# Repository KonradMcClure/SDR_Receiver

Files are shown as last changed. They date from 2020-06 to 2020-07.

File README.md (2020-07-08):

# Low-Cost Software Defined Radio Receiver
The goal of this project was to design a low-cost software-defined radio (SDR) receiver. This project was done for my Walla Walla University Electronics II course with my partner [Caleb Froelich](https://github.com/froeca).

## Design Objectives
Our professor, [Dr. Rob Frohne](https://github.com/frohro), gave us the following design objectives:
  1. Minimum discernible signal less than 1 uV
  2. Good image rejection
  3. Low noise figure
  4. Inexpensive to build ($25 component budget)
  
My partner, Caleb, and I set our own design objectives as well to help narrow down the design we settled on:
  1. **Simple Design**: We wanted our design to be easy to understand and construct. As such we avoided using transformers and used a Tayloe Mixer which has a relatively easy to understand design.
  2. **Ease of Construction**: Since this class took place during an online quarter due to COVID-19, we wanted to make sure construction wouldn't be too difficult without the usual tools we have in our lab. This decision shaped our board layout and part selection (picking through-hole parts as opposed to surface-mount when possible).
  3. **Ease and Quality of Amplification**: Most of the cost that goes into the board went into getting good, low-noise operational amplifiers. The instrumentation amps we chose use a single resistor to set the gain, making it easy to switch out and test different gain values.

## Overview
The Software Defined Radio (SDR) receiver connects to an antenna and covers the filtering, mixing, and amplification of the desired signal. It then connects a sound card within a computer and software handles the demodulation of the signal into playable audio. The mixing is handled using an Arduino Nano running code provided to us by our Professor, [Dr. Rob Frohne](https://github.com/frohro), which interfaces with [Quisk](https://james.ahlstrom.name/quisk/), an SDR that controls the receiver through the Arduino. Using Quisk, the radio can be tuned to a certain frequency by adjusting the speed of the local oscillator used in the mixing process. Our budget on this project to keep with the low-cost aspect was about $30 including fabrication of the PCB and the required components. 

# Theory
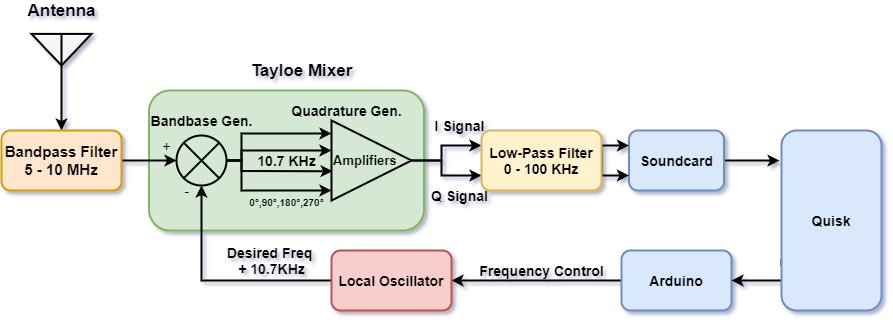
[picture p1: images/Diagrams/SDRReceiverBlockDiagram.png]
Circuit Block Diagram

The basics of the SDR Receiver are shown above in the block diagram, with the blue components being defined by software. An antenna picks up the radio signal and passes it through a bandpass filter. This filter will attenuate any signals outside our desired range of 5 – 10 MHz. This is then passed through a Tayloe Mixer, also known as the Tayloe Quadrature Product Detector. The Tayloe Mixer is a simple and efficient mixer that uses a 1:4 demultiplexer and operational amplifiers to generate the I and Q quadrature signals for demodulation. After the signal has been split into four bandbase signals, they are amplified and combined into the I and Q quadrature signals. Those signals go through a final Low-Pass filter that will attenuate signals above 100KHz in frequency, effectively smoothing the output signal. This signal is then sent via 3.5mm audio cable to the soundcard which demodulates the signal. Quisk can then read the input from the sound card and play it. Quisk also interfaces to the Arduino Nano to set the speed of the local oscillator for tuning into the desired frequency.

# Rev 2 Design
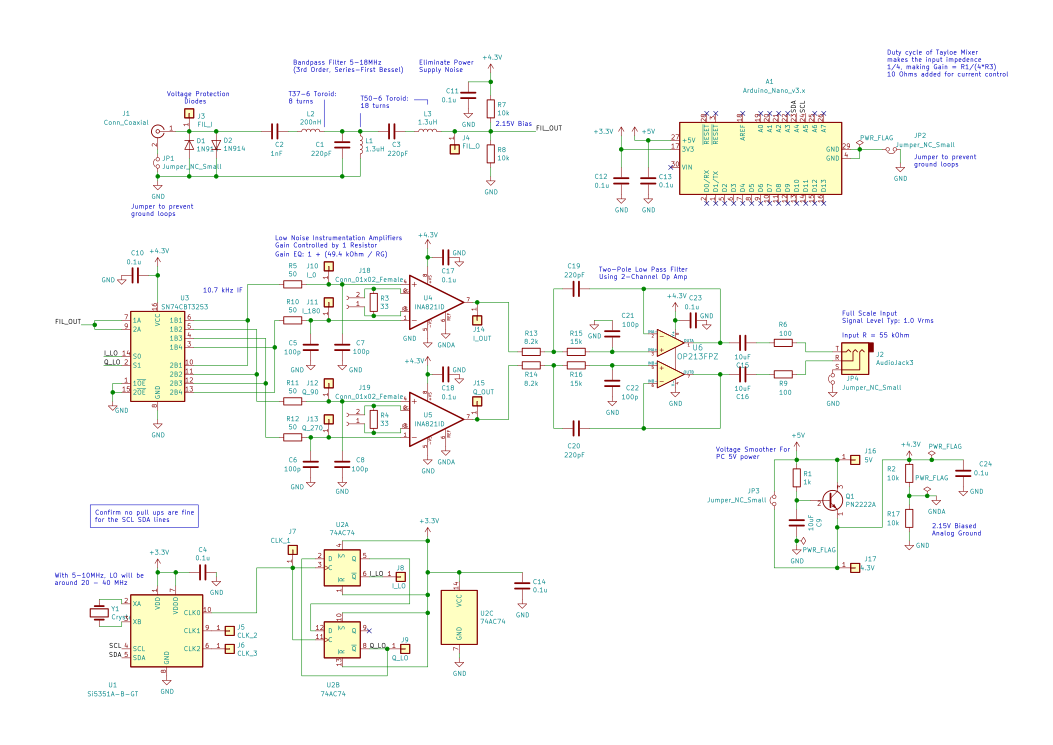
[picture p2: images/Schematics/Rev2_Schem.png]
Rev 2 Schematic


Here is the full design schematic, which we'll break down piece by piece below. You can look at the full image [here](https://github.com/KonradMcClure/SDR_Receiver/blob/master/images/Schematics/Rev2_Schem.svg) or download the [KiCad](https://kicad-pcb.org/) project [here](https://github.com/KonradMcClure/SDR_Receiver/tree/master/SDRReciever) to take a closer look yourself.

This page is also acting as a report of the design we had for our class project. If the design is continued on in the future, I will likely move this description to the Wiki and update it with the new one.

## Bandpass Filter
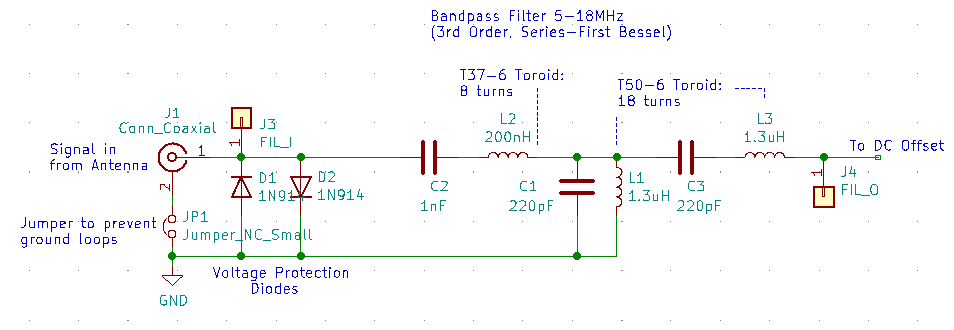
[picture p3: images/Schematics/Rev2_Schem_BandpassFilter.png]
Bandpass Filter Rev2


The bandpass filter is a 3rd-Order, Series-First, Bessel filter that was generated using the RF Tools LC Filters Design Tool. It is designed to have input and output impedances of 50 Ω. The motivation to use a series-first configuration came from the capacitor C2 acting as a blockade for any DC signal coming in through the antenna. This would allow us better control over the DC voltage offset that is later required for our single-supply op-amps. 

## DC Voltage Offset
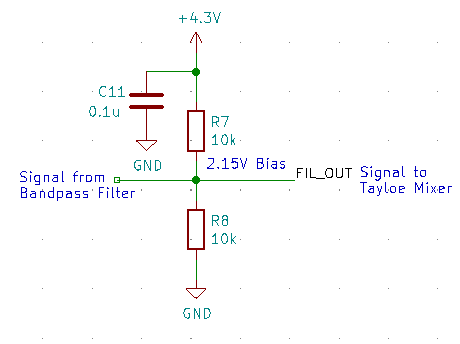
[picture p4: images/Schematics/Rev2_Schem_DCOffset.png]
DC Voltage OFfset Rev 2


Since we didn't want to create a negative supply for our op-amps, we opted for using them with a single supply and giving our signal a DC offset that sits in the middle between the 4.3V supply and ground. This offset was done via a simple voltage divider of two 10k resistors from 4.3V to GND.

## Tayloe Mixer 
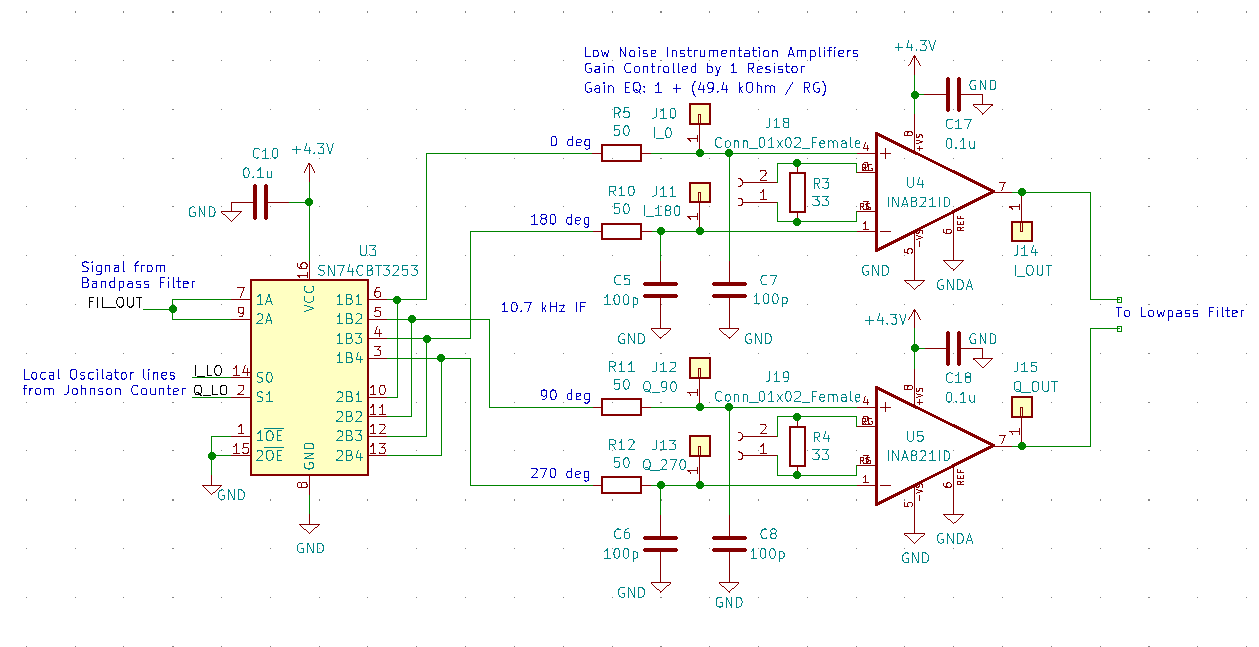
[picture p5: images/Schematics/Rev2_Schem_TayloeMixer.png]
Tayloe Mixer Rev 2


The Tayloe Mixer is a mixer design as seen in [this paper](http://www.norcalqrp.org/files/Tayloe_mixer_x3a.pdf) by Dan Tayloe. We chose it due to its relatively simple and elegant design. It utilizes a [two-channel SN74CBT multiplexer](http://www.ti.com/lit/ds/symlink/sn74cbt3253.pdf?ts=1591655665924) and a pair of [INA821ID single gain resistor instrumentation amplifiers](http://www.ti.com/lit/ds/symlink/ina821.pdf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). To be more specific, Tayloe describes this as a "switching integrator," rather than a mixer, since a mixer normally produces both a sum and difference frequency of the RF and LO signals, while this design only produces the difference frequency. Acknowledging this, I am going to refer to it as a mixer for simplicity.

### Multiplexer
The [SN74CBT multiplexer](http://www.ti.com/lit/ds/symlink/sn74cbt3253.pdf?ts=1591655665924) acts as a [product detector](https://en.wikipedia.org/wiki/Product_detector), converting the RF signal into four baseband signals. The switching speed of the MUX is set by the local oscillator, which is a divide by 4 circuit created from a 2-bit Johnson counter seen below. This speed is set to be the RF frequency + 10.7kHz. The sampling capacitors shown between the MUX and instrumentation amps will follow the voltage level of the signal while its line's switch is active, and then hold that value while the switch is closed. This will occur on four different lines, outputting four bandbase signals at phases of 0°, 90°, 180°, and 270°. 

### Instrumentation Amplifiers
The [INA821ID Instrumentation Amplifiers](http://www.ti.com/lit/ds/symlink/ina821.pdf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) act as differential summers of the 0° and 180° signals, and the 90° and 270° signals. This is because the information between the two signals within the two pairs are redundant to each other. Summing 0° and 180° will get us our In-Phase (I) signal and summing the 90° and 270° signals will get us our Quadrature (Q) signal.

## Lowpass Filter
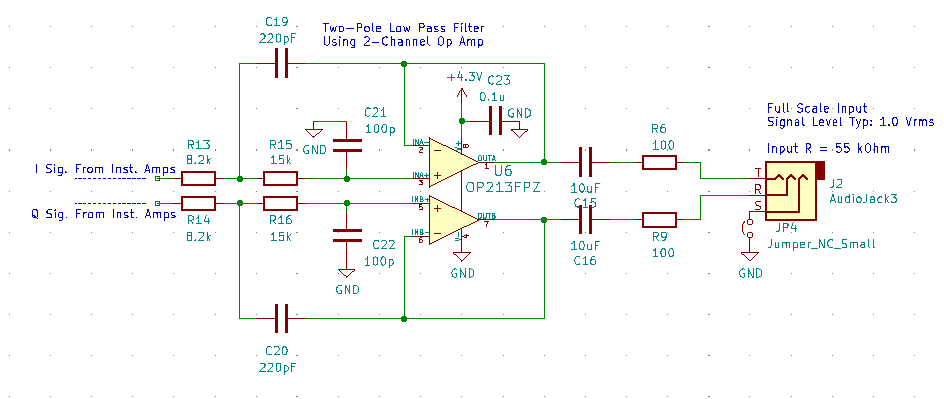
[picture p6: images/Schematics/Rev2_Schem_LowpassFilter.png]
Lowpass Filter


Now that we have our I and Q signals, we'll send them through a Lowpass filter that will attenuate the high frequencies that may still remain in the signal, effectively smoothing it out. For this we used an [OP213FPZ op amp](https://www.analog.com/media/en/technical-documentation/data-sheets/OP113_213_413.pdf), which has 2-channel produces low noise. We used the [Texas Instruments Filter Design Tool](https://webench.ti.com/filter-design-tool/) to generate this as a two-pole filter with a 100kHz cutoff and no gain.

## Voltage Smoother and Analog Ground Reference
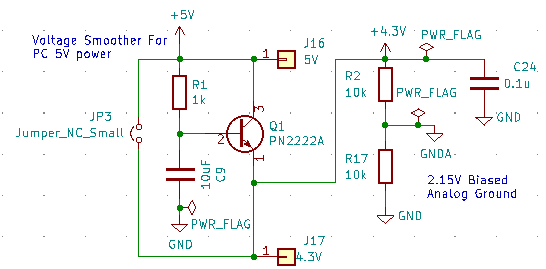
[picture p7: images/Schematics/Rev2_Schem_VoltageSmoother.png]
Voltage Smoother Rev2


Professor Rob Frohne suggested that we all use a BJT to smooth the voltage coming from the computer, since all the rapid switching that happens in computers tends to create a lot of noise. He measured the output voltage to be about 4.3V based on the design on [his GitHub](https://github.com/frohro/IQ_SDR) , so we followed his example and designed ours the same way.

# Simulation
We simulated each of our main parts in LTspice to confirm our design. Some things, 

## Bandpass Filter Simulation
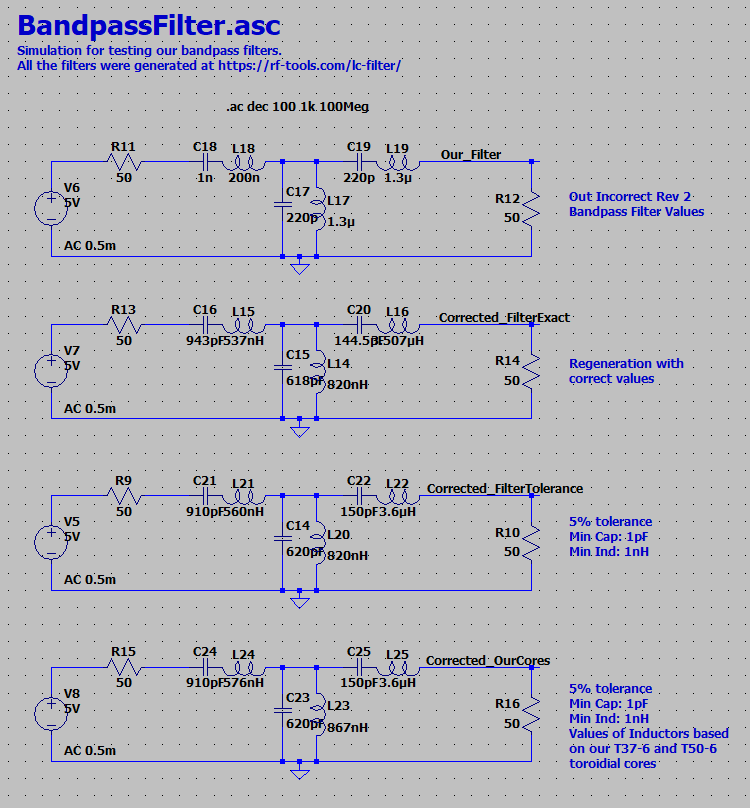
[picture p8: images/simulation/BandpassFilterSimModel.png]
Bandpass Filter Simulation Model

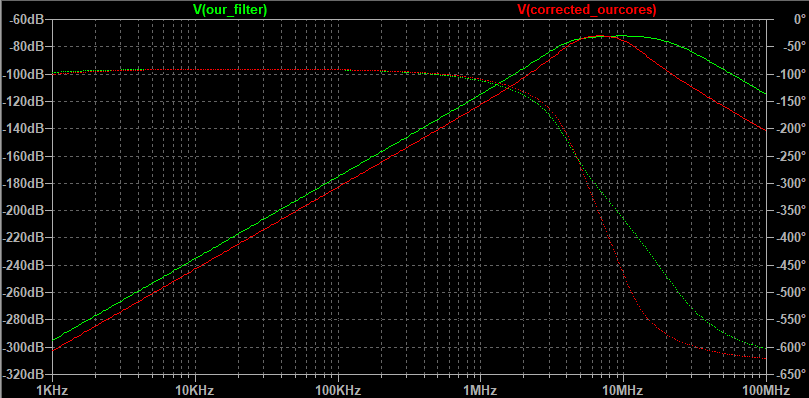
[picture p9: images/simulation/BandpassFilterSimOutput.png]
Bandpass Filter Simulation Output


First we simulated the bandpass filter to check it's response. As seen here, and as mentioned later, our bandpass filter for Rev 2 got it's values messed up, which led to a similar, but incorrect response. We re-ran the RF Tools filter design and retested the response of our new filter in LTspice. As can be seen above, the response is much better. The filter on the bottom is calculated with 5% tolerances on all the components and then adjusted for the same toroids that we were provided by our professor. The differences between the bottom three are neglible, so only our current filter and the final adjusted one is plotted.

## Lowpass Simulation
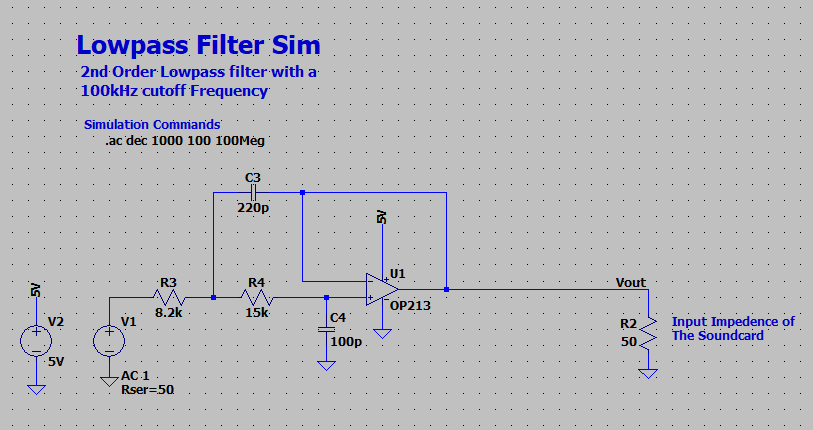
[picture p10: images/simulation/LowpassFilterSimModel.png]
Lowpass Filter Simulation Model

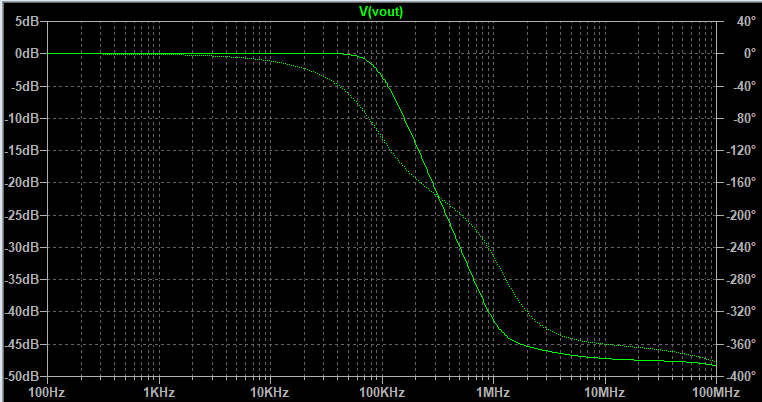
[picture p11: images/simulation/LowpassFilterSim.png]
Lowpass Filter Simulation Output


We also tested out our lowpass filter. Luckily LTspice had the OP213's built-in, so we were confident in the results. We can see that the cutoff is at 100kHz as we expected. 

## Full Design Simulation
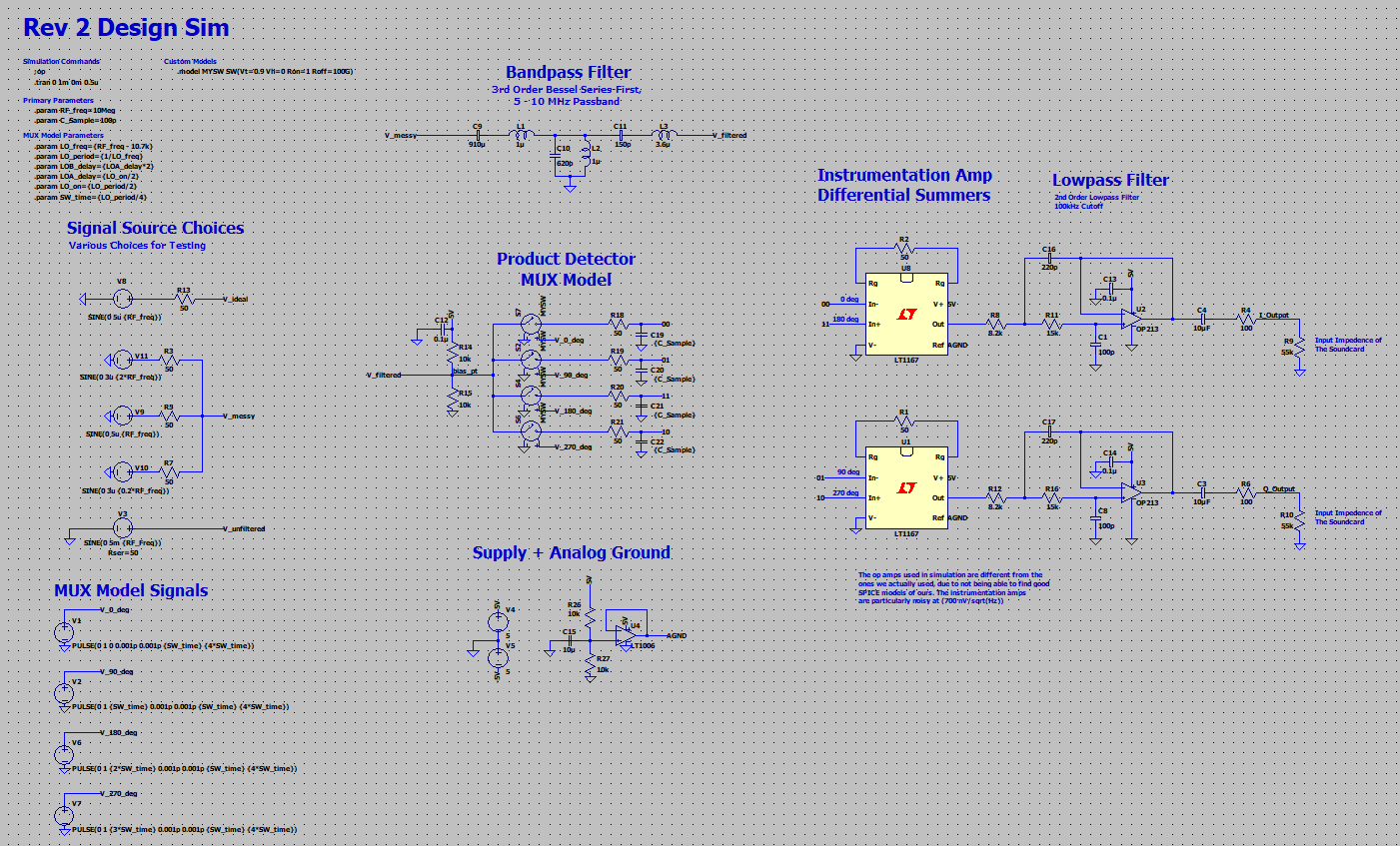
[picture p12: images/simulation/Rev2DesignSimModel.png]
Full Rev 2 Simulation Model


With the two filters out of the way, we can assemble the components inbetween. We have created a model for the mux using four voltage controlled switches, and four voltage pulses that control them in the same manner that the Johnson counter will. For instrumentation amps, we used LT1167s because they didn't take as long to simulate as long as ones we tried to import. The LT1167's had a much higher noise profile than the INA821's we selected, so we figured if we could get these to work, the INA821's would work great. below you can see the baseband signals and the I and Q outputs. They're exactly as we'd like to see them, about 90 degrees out of phase and at a frequency of about 10.8kHz.

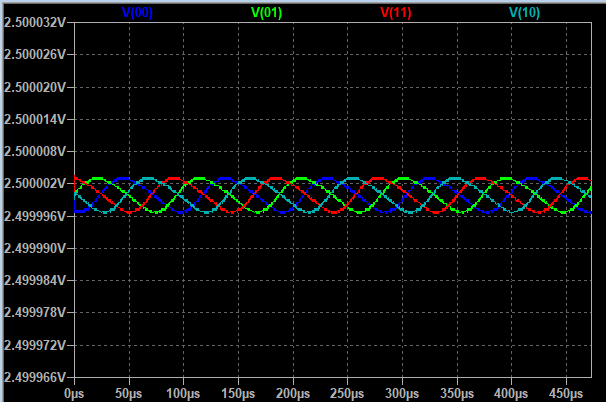
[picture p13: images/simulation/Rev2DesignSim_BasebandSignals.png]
Full Rev 2 Simulation Baseband Output

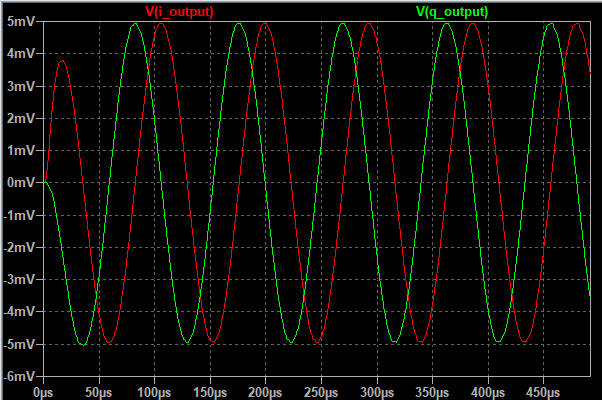
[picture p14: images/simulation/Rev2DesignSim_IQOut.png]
Full Rev 2 Simulation I and Q Output


# PCB Design
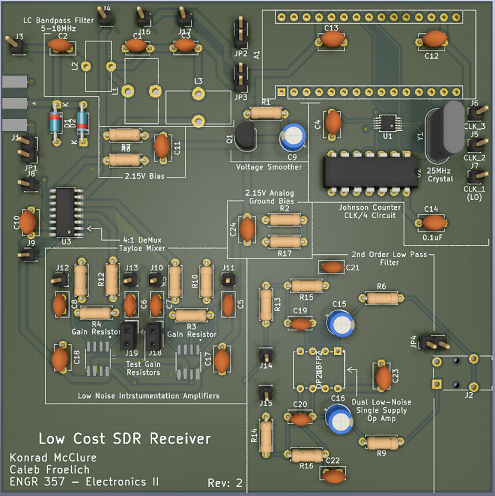
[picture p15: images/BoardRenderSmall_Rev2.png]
Board Render


We sourced our board from [JLCPCB](https://jlcpcb.com/), who had an offer going of 5, 2-layer, 100x100mm boards for $2. With that size in mind, my partner and I both did our own board layouts and compared after to decide which to send in for printing. We wanted to be sure to match the impedance of the antenna all the way through to the instrumentation amps, so we used the PCB Calculator in KiCad to find the trace width we needed: 1.064mm. The input to the calculator can be seen here:
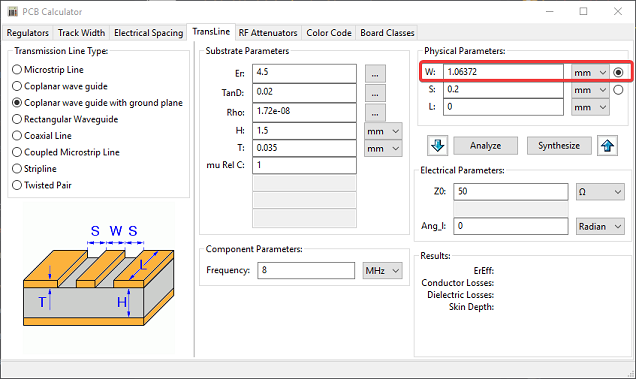
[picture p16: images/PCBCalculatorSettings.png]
PCB Calculator Screen


We got the rest of the information, such as the substrate parameters, from [JLCPCB's Capabilities page](https://jlcpcb.com/capabilities/Capabilities). The design shown above was mine, doing my best to keep traces relatively short and straight and parts close to the next. However...

# Construction and Testing
The PCB layout we decided to print was my partner's who had a layout with really nice divisions between sections, which we believed would be easier for testing. You can find that layout on [his GitHub page](https://github.com/froeca/Software-Defined-Radio). All of the components are exactly the same, only the layout is different.

Before receiving the parts from Dr. Frohne, JLCPCB, and Digikey, we put together a Construction and Testing plan which can be found in the documents folder of this repository. This plan wasn't followed exactly to the T during our assembly, but it was an important step for us thinking through the process and how to best assemble the sections so that we could test them in isolation before connecting them together.

# Testing
For info on the testing of the project, head over to the [Testing page on the Wiki](https://github.com/KonradMcClure/SDR_Receiver/wiki/Rev-2-Testing)!

# Quisk Setup
Loading the Arduino Nano with the OpenRadio software found [here](\Arduino\PSK), I opened the quisk_conf_openradio.py file and change the info in the SERIAL PORT SETTINGS sections to the COM# port that my Arduino is plugged into. This was found in Device Manager on Windows 10. In Device Manager, I also right clicked the COM port and went to Properties > Port Settings and changed the Bits per second to 57600 to match the value in the config file.

After opening Quisk, I went to Config > Radios and added a radio of the type SoftRock Fixed and named it MyRadioBoy (not necessary), setting it to open to that new radio. Under the new MyRadioBoy tab and Hardware subtab, I changed the Hardware File Path to point to the quisk_conf_openradio.py in the repository. Then in the Sound subtab, I made sure the I/Q Rx Sample Input was set to the sound card input that my 3.5mm cable was connected to from the board.

# Results!
Sending in a 8MHz test frequency, I could see that the image rejection was pretty good, but I went to the Config tab and clicked the "Adjust receive amplitude and phase" button. **I adjusted the levels for the best image rejection I could get, dropping the image down to about the same level as the spurious signals.**

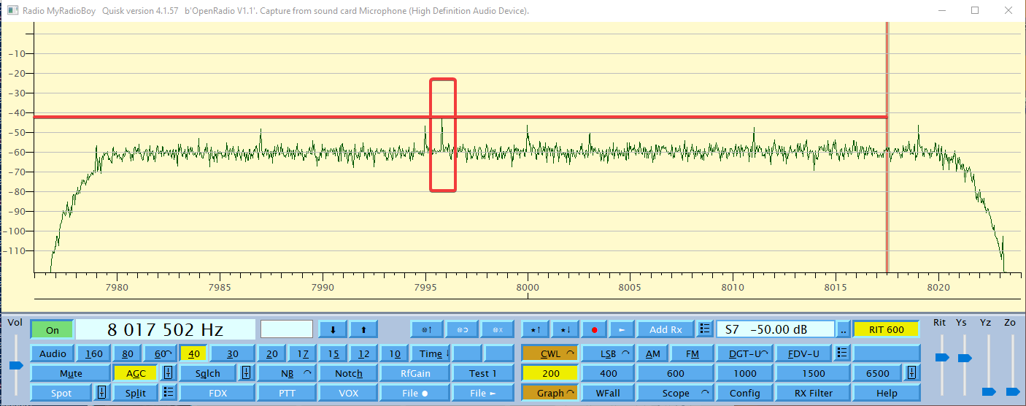
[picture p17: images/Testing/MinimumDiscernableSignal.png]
Minimum Discernable Signal Test

Then, using a step attenuator Caleb and I designed before this radio, I input a 50uV 8MHz signal to the receiver and attenuated it by 40dB, which was just higher than the spurious signals. **From this I concluded our minimum discernable signal was about 0.5uV.**

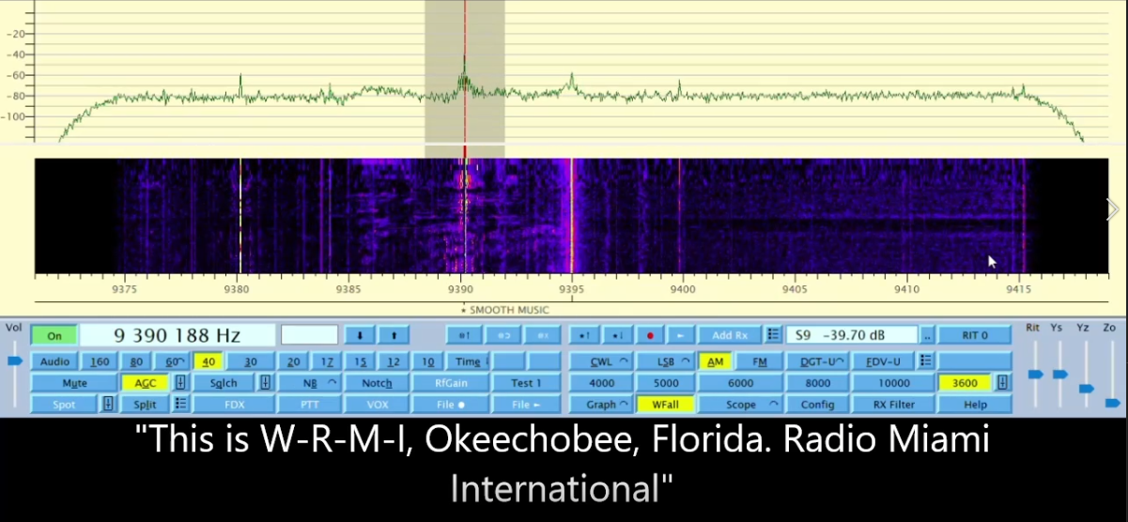
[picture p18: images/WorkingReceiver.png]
It works!

After stringing a wire out to my roof as an antenna (about 50ft up or so) and soldering one end to an SMA connector, I connected it to the board. While not the clearest, it picks up signals pretty well! [You can see some signals that I was able to receive here!](https://github.com/KonradMcClure/SDR_Receiver/tree/master/video)

# Credits
My teammate [Caleb Froelich](https://github.com/froeca), who has [his own repository of this project](https://github.com/froeca/Software-Defined-Radio).

My professor [Dr. Rob Frohne](https://github.com/frohro), who provided us with an example of a similar [project of his own here](https://github.com/frohro/IQ_SDR)!

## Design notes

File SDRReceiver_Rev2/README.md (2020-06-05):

# SDR_Receiver
Software Defined Radio Receiver designed together with Caleb Froelich for our Walla Walla University Electronics II project.

## Board Design
IMAGE

Designed on a 100mm x 100mm Board...

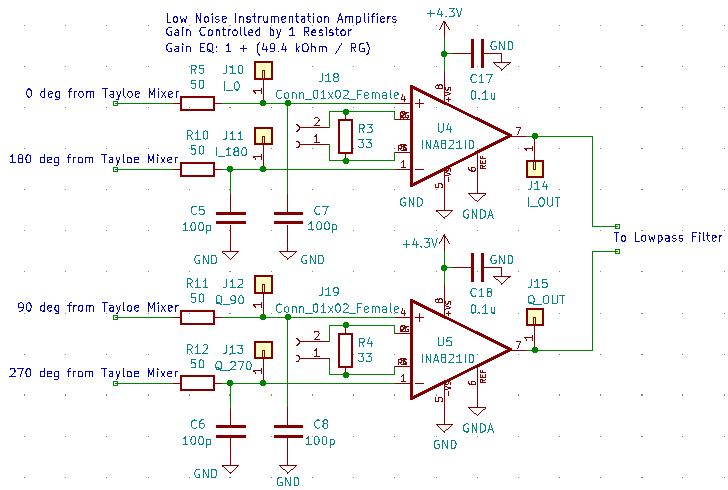
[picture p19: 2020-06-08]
images/Schematics/Rev2_Schem_InstAmps.png

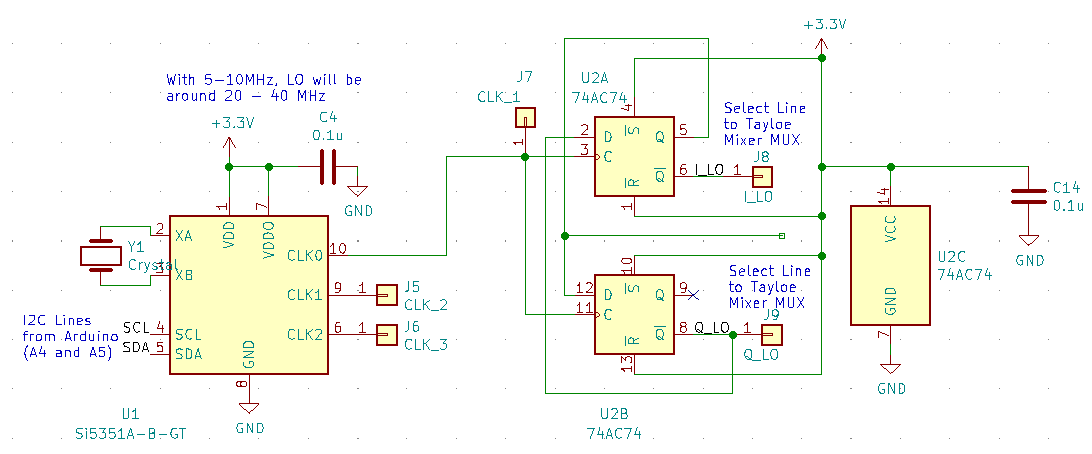
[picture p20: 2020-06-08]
images/Schematics/Rev2_Schem_CLKGenAndDiv4.png

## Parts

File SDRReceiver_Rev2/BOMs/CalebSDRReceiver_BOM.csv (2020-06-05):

Manufacturer Part Number | Manufacturer | Digi-Key Part Number | Customer Reference | Reference Designator | Packaging | Part Status | Quantity | Unit Price | Extended Price | Quantity Available | Mfg Std Lead Time | Description | RoHS Status | Lead Free Status | REACH Status
ATS250 | CTS-Frequency Controls | CTX419-ND | Caleb Froelich (1/12) 1pc |  | Bulk | Active | 1 | 0.37 | $0.37 | 238 | 12 Weeks | CRYSTAL 25.0000MHZ SERIES T/H | ROHS3 Compliant | Lead free | REACH Unaffected
INA821IDR | Texas Instruments | 296-INA821IDRCT-ND | Caleb Froelich (2/12) 2pc |  | Cut Tape (CT) | Active | 2 | 5.15 | $10.30 | 1963 | 6 Weeks | OP AMP | ROHS3 Compliant | Lead free | Not Available
SR215C104KAR | AVX Corporation | 478-3188-ND | Caleb Froelich (3/12) 10pc |  | Bulk | Active | 10 | 0.135 | $1.35 | 8242 | 11 Weeks | CAP CER 0.1UF 50V X7R RADIAL | ROHS3 Compliant | Lead free | REACH Unaffected
K101K15C0GF53L2 | Vishay BC Components | BC5130-ND | Caleb Froelich (4/12) 6pc |  | Bulk | Active | 6 | 0.22 | $1.32 | 6218 | 10 Weeks | CAP CER 100PF 50V C0G/NP0 RADIAL | ROHS3 Compliant | Lead free | Not Available
SI5351A-B-GT | Silicon Labs | 336-2399-5-ND | Caleb Froelich (5/12) 1pc |  | Tube | Active | 1 | 0.92 | $0.92 | 1436 | Not Available | IC CLK GENERATOR 200MHZ 10MSOP | Not Available | Lead free | Not Available
SN74AC74N | Texas Instruments | 296-4342-5-ND | Caleb Froelich (6/12) 1pc |  | Tube | Active | 1 | 0.55 | $0.55 | 811 | 6 Weeks | IC FF D-TYPE DUAL 1BIT 14DIP | ROHS3 Compliant | Lead free | REACH Unaffected
8.6002E+11 | Würth Elektronik | 732-8820-1-ND | Caleb Froelich (7/12) 3pc |  | Cut Tape (CT) | Active | 3 | 0.1 | $0.30 | 2960 | 28 Weeks | CAP ALUM 10UF 20% 25V RADIAL | ROHS3 Compliant | Lead free | REACH Unaffected
SN74CBT3253CDR | Texas Instruments | 296-19206-1-ND | Caleb Froelich (8/12) 1pc |  | Cut Tape (CT) | Active | 1 | 0.58 | $0.58 | 5969 | 6 Weeks | IC MUX/DEMUX DUAL 4:1 16SOIC | ROHS3 Compliant | Lead free | REACH Unaffected
OP213FPZ | Analog Devices Inc. | OP213FPZ-ND | Caleb Froelich (9/12) 1pc |  | Tube | Active | 1 | 7.47 | $7.47 | 334 | 8 Weeks | IC OPAMP GP 2 CIRCUIT 8DIP | ROHS3 Compliant | Lead free | REACH Unaffected
PN2222ATF | ON Semiconductor | PN2222ATFCT-ND | Caleb Froelich (10/12) 1pc |  | Cut Tape (CT) | Active | 1 | 0.24 | $0.24 | 7314 | 19 Weeks | TRANS NPN 40V 1A TO-92 | ROHS3 Compliant | Lead free | REACH Unaffected
D102K20Y5PH63J5R | Vishay BC Components | BC5111-ND | Caleb Froelich (11/12) 1pc |  | Bulk | Active | 1 | 0.18 | $0.18 | 16259 | 10 Weeks | CAP CER 1000PF 100V Y5P RADIAL | ROHS3 Compliant | Lead free | Not Available
K221K10X7RF5UH5 | Vishay BC Components | BC2672CT-ND | Caleb Froelich (12/12) 4pc |  | Cut Tape (CT) | Active | 4 | 0.19 | $0.76 | 13768 | 10 Weeks | CAP CER 220PF 50V X7R RADIAL | ROHS3 Compliant | Lead free | Not Available

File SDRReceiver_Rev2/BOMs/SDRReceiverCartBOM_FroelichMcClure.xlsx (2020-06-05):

 | Digikey BOM - Konrad McClure and Caleb Froelich
 | Cart Link | https://www.digikey.com/short/zzpdh8
Index | Quantity | Part Number | Manufacturer Part Number | Description | Customer Reference | Available | Backorder | Unit Price | Extended Price USD
1 | 1 | CTX419-ND | ATS250 | CRYSTAL 25.0000MHZ SERIES T/H |  | 1 | 0 | $0.37 | $0.37
2 | 2 | 296-INA821IDRCT-ND | INA821IDR | OP AMP |  | 2 | 0 | 5.15 | 10.30
3 | 10 | 478-3188-ND | SR215C104KAR | CAP CER 0.1UF 50V X7R RADIAL |  | 10 | 0 | 0.14 | 1.35
4 | 6 | BC5130-ND | K101K15C0GF53L2 | CAP CER 100PF 50V C0G/NP0 RADIAL |  | 6 | 0 | 0.22 | 1.32
5 | 1 | 336-2399-5-ND | SI5351A-B-GT | IC CLK GENERATOR 200MHZ 10MSOP |  | 1 | 0 | 0.92 | 0.92
6 | 1 | 296-4342-5-ND | SN74AC74N | IC FF D-TYPE DUAL 1BIT 14DIP |  | 1 | 0 | 0.55 | 0.55
7 | 3 | 732-8820-1-ND | 860020472003 | CAP ALUM 10UF 20% 25V RADIAL |  | 3 | 0 | 0.10 | 0.30
8 | 1 | 296-19206-1-ND | SN74CBT3253CDR | IC MUX/DEMUX DUAL 4:1 16SOIC |  | 1 | 0 | 0.58 | 0.58
9 | 1 | OP213FPZ-ND | OP213FPZ | IC OPAMP GP 2 CIRCUIT 8DIP |  | 1 | 0 | 7.47 | 7.47
10 | 1 | PN2222ATFCT-ND | PN2222ATF | TRANS NPN 40V 1A TO-92 |  | 1 | 0 | 0.24 | 0.24
11 | 1 | BC5111-ND | D102K20Y5PH63J5R | CAP CER 1000PF 100V Y5P RADIAL |  | 1 | 0 | 0.18 | 0.18
12 | 4 | BC2672CT-ND | K221K10X7RF5UH5 | CAP CER 220PF 50V X7R RADIAL |  | 4 | 0 | $0.19 | $0.76
 |  |  |  |  |  |  |  | TOTAL: | $24.34

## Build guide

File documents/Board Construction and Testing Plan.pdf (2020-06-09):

Caleb Froelich | ENGR 357
Konrad McClure
05/07/2020

### Board Construction and Testing Protocol

Prep-Work
- Prepare documentation

Attenuator:
- Visually inspect the PCB board.
- Check resistance values.
- Solder ‘em boys up.
- Test all the stage combinations using our Digilent Discovery 2.
- Use 50 ohm resistor on the end of the attenuator.

SDR Receiver:
- Check all the parts.
- Assemble inductors.
- L1: | T37-6: 8 turns.
- L2 + L3: | T50-6: 18 turns.
- Organize parts by section. Note orientation of IC’s and polarized(?) capacitors.
- Visually inspect the PCB board.
- Test NET connections to confirm.
- Start assembling PCB boards by section. (In a given section, do surface mount first.)
- Check Discovery 2 to see if they have 50 ohm input.
- Solder SMA connector.
- Bandpass Filter Section.

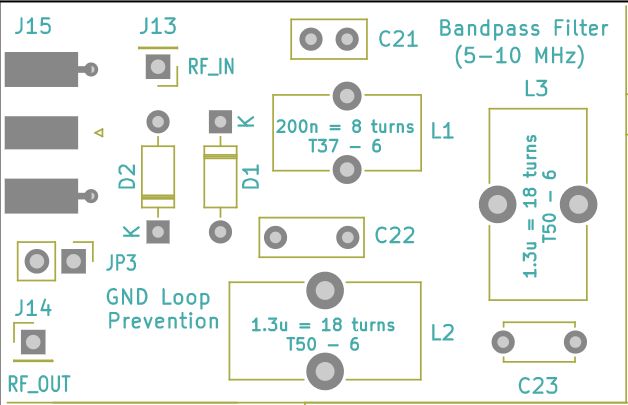
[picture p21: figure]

- Solder bandpass filter and components.
- ⚠ Test power connection for shorts ⚠
- Test with Discovery 2, send a small signal in and measure the output voltage. We will compare the measurements with our LTSPICE simulation data.

05/07/2020
- Digital Section.

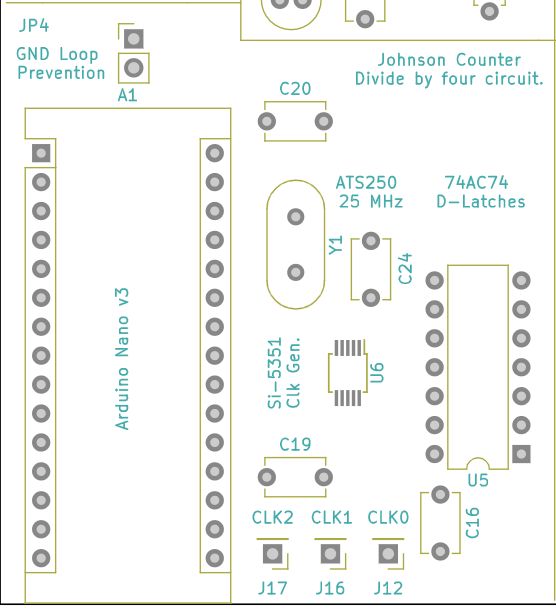
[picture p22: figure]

- Solder pin sockets and place Arduino. (Solder bypass capacitors)
- ⚠ Test power connection for shorts ⚠
- Isolate code into test files to test specific sections of the board.
- Install 2.15V biased analog ground.
- ⚠ Test power connection for shorts ⚠
- Make sure we have a 50 ohm load for testing purposes.
- Solder clock generator.
- ⚠ Test power connection for shorts ⚠
- Download test program from github.
- https://github.com/frohro/IQ_SDR/tree/master/Quisk/Arduino/SDR_Test1 (https://github.com/frohro/IQ_SDR/tree/master/Quisk/Arduino/SDR_Test1)
- Test power.
- Test clock generator. The scope of the Discovery 2 has 30MHz of bandwidth. Since our clock is maximally going to be switching at 40MHz, we will have to refine the test such that we can use the scope on the Analog discovery 2..
- Solder crystal.
- Solder D-latches. (Bypass capacitors)
- ⚠ Test power connection for shorts ⚠
- Test Johnson Counter. We have two test points to check LO_Q and LO_I. We will be testing to ensure that these are 90

o out of
phase.

05/07/2020
- Low-pass Filter Section. (Solder bypass capacitors for op amps)

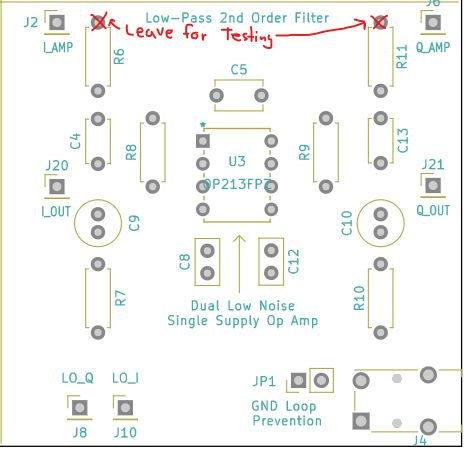
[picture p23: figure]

- Solder the 2nd order low-pass filter along with capacitors and resistors.
- ⚠ Test power connection for shorts ⚠
- Solder only the filter-side of R6 and R11 at first, using the other end for the signal generator probe. This will keep it isolated until it’s time to connect it to the rest of the circuit.
- Similar testing procedure to the Bandpass filter, send a small signal from the Discovery 2 and measure the output for various frequencies. We will compare the measurements with our LTSPICE simulation data.
- Instrumentation Amp Section

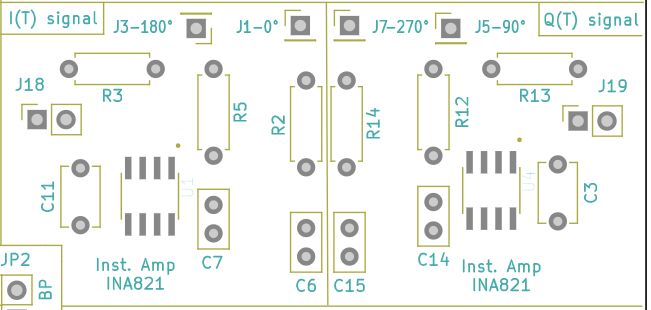
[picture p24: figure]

- Solder instrumentation amps and bypass capacitors.
- ⚠ Test power connection for shorts ⚠
- Test common mode rejection of instrumentation amps and differential gain:
- Send a signal through the I_IN0, I_IN180 and Q_IN90, Q_IN270 test points with the Discovery 2’s signal generator and measure the output on the corresponding output test point.

05/07/2020
- The common mode rejection could be measured by applying a DC bias to the input signal.
- The differential gain can be measured and varied by adding parallel resistance to pins J18 and J19. This would decrease the gain resistance and increase the gain.
- Tayloe Mixer Section

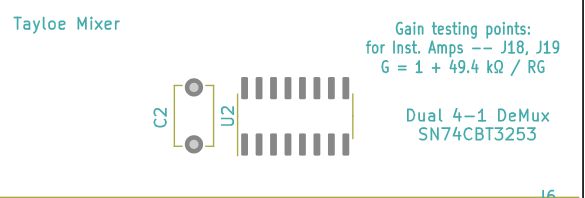
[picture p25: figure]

- Multiplexer. (Bypass capacitors and gain resistors and other throughhole parts.)
- ⚠ Test power connection for shorts ⚠
- Send a DC voltage through the mux and view the outputs.
- Test sound card.
- Plug it in, test with operating system
- Make sure that you can select sound card with Quisk.
- Test microphone input with microphone/headphones/cable; whatever is available.
- Load arduino code
- Check for shorts using a multimeter.
- Vcc to GND.
- Analog GND to GND.
- Hook it all up.
- Send a sinusoidal signal (use attenuator) through the bandpass filter from the Digilent.
- Monitor the current drawn from the power supply. Start out with 0 volts and then turn it up.
- Fry it 🔥🔥🔥.
- Test which GND loop produces the least noise.

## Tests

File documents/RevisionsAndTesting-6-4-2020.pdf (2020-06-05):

Konrad McClure | ENGR 357 | 6/4/2020

## Revisions and Testing

The Board Is All Over the Place

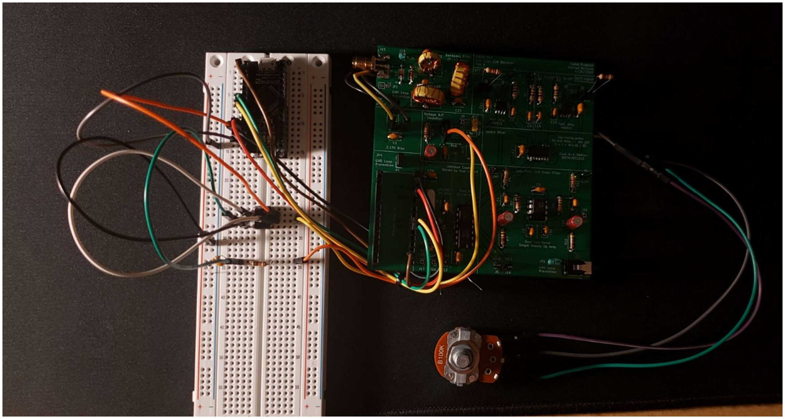
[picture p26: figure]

Figure 1 - Board prototype as is. Arduino and voltage buffer for setting GNDA are on the left. Potentiometer shown below for adjusting the input voltage offset.

Corrected Issues

Op Amp Voltage Buffer

Caleb was nice enough to mail me one of his LM741 Op Amps to set up a voltage buffer with. It appears to correct the output impedance problem. It is now set up on the breadboard like so:

SDA and SCL Lines

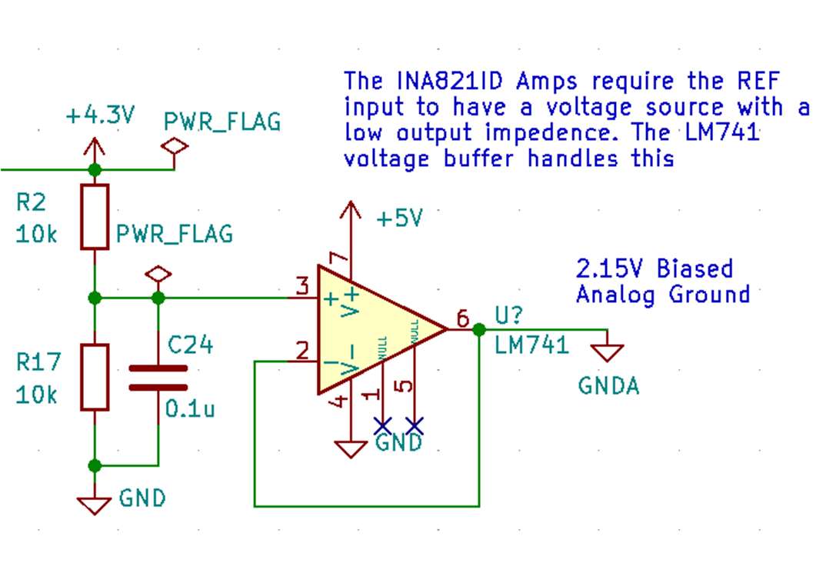
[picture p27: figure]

As it turns out, on Caleb’s schematic he had accidentally placed the I2C lines on A3 and A4 instead of A4 and A5. Since those are hardware-based and cannot be changed, we had to move the Arduino to the breadboard and re-route the pins via wire jumpers. We could have tried to cut traces, but we didn’t want to risk damaging the board if there was a safer way.

New Issues

MUX Problem (Fixed!)

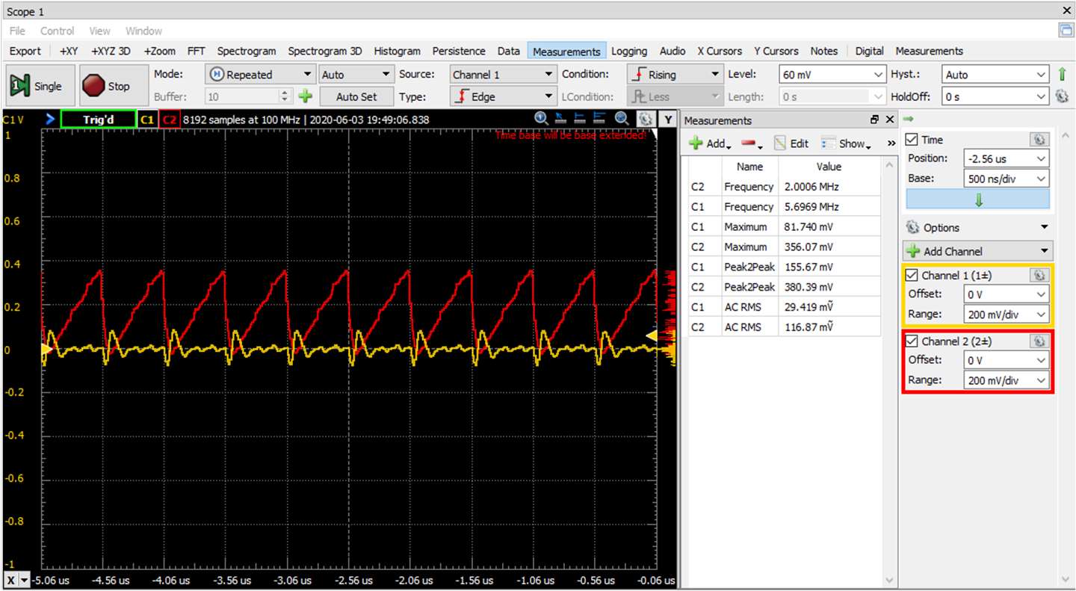
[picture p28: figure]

Figure 2 - Signals seen on either side of bandpass filter even when no signal was input on antenna YELLOW = RF_IN Pin, RED = RF_OUT Pin.
After correcting the previous problems, I saw that, with no signal input on the antenna, the above noise appeared on either side of the bandpass filter. When putting a signal in, this noise would overpower it. The frequency of the signal was equal to that of my LO signals, so I determined it must have been coming from there somehow. At Dr. Frohne’s suggestion, I dialed the clock generator back so that the LO signal would be at 3kHz so it would be easier to see the signal. Using the RF_OUT jumper pin, I put a 1V DC signal directly into the input of the MUX to observe the switching behavior. The results can be seen below

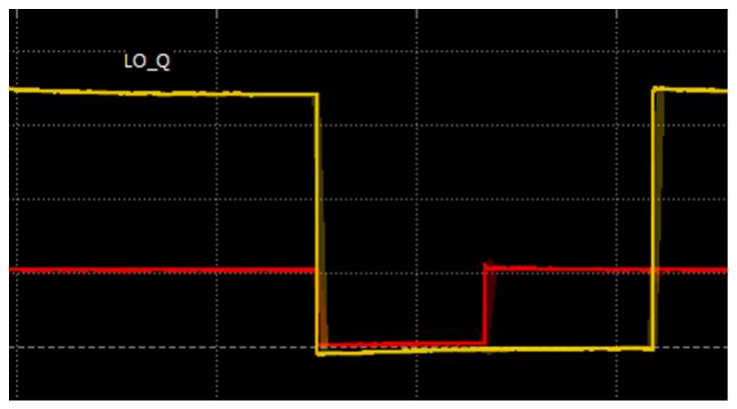
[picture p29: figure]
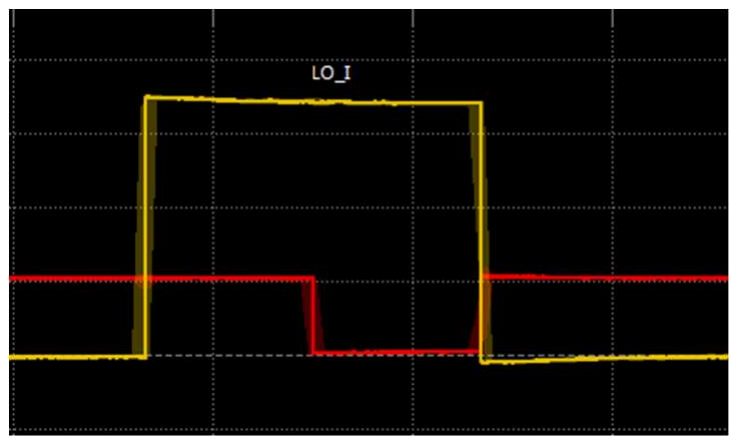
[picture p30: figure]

Figure 3 - RED = input signal at RF_OUT (1V DC), YELLOW = LO_I or LO_Q

On the MUX, LO_I = S0 (low bit), LO_Q = S1 (high bit). If we look at the input and LO signals together, we can see that the input signal is connected to ground at the 01 state of the MUX. Visually observing the board, I found that the capacitor C14’s legs were touching on the back side. After clipping them, the problem disappeared for both the low and high frequency cases.

Voltage Offset Matching (Fixed! Kind of)

After adding the Op Amp Voltage Buffer, I still found that the voltages at the two 10k-10k dividers (GNDA divider and RF_OUT bias point) were off by about 40mV, causing the instrumentation amps to saturate from amplifying the difference. Luckily, I had a 100k potentiometer handy that I first tried to use to replace the GNDA divider with the potentiometer, however no matter how I adjusted it, I couldn’t set GNDA low enough to meet the bias point. GNDA would not go lower than 1.96mV while the bias point was around 1.90mV. (These voltages are lower than expected, but that’s another matter for now.) As a second attempt, I replaced the bias point instead, which did allow me to tune the bias to be equal with GNDA.

MUX Output at Different Offsets (In Progress: https://github.com/KonradMcClure/SDR_Receiver/issues/3)

The I_0, I_180, Q_90, and Q_270 lines are not at equal voltage offsets, causing the I and Q signals to be about a full volt apart. Need to compare their offsets to GNDA and find a way to get those paths at as close resistances to each other as possible, while also averaging on GNDA...

Arduino 5V Pin Voltage Too Low (In Progress: https://github.com/KonradMcClure/SDR_Receiver/issues/2)

The voltage reads around 4.5V. There's probably something pulling more current than it should. After the BJT smoother, we're aiming for a voltage of about 4.3V, but with the drop from 5V causes it to be around 3.8-3.9V

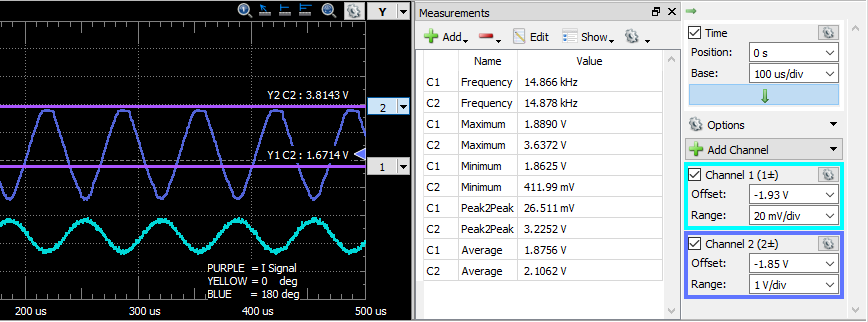
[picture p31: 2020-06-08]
images/Testing/InstTest_I-Sig_180deg.png

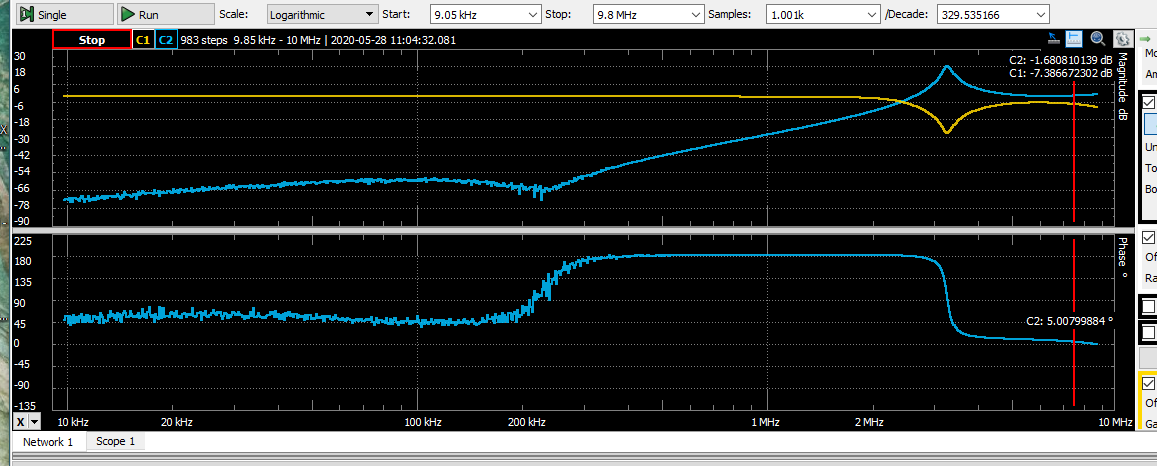
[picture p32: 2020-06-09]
images/Testing/BandpassFilterTest.png

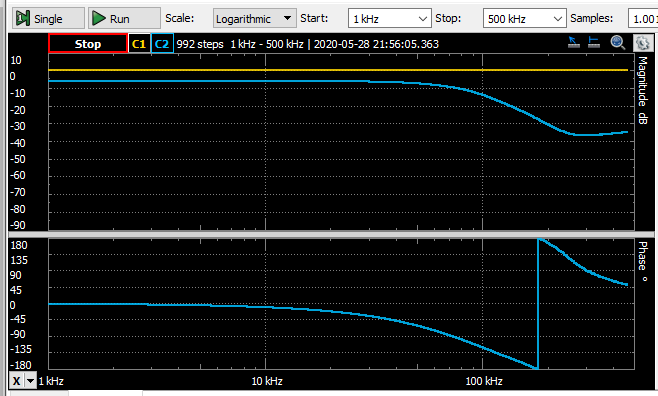
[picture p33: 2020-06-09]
images/Testing/LowpassFilterTest.png

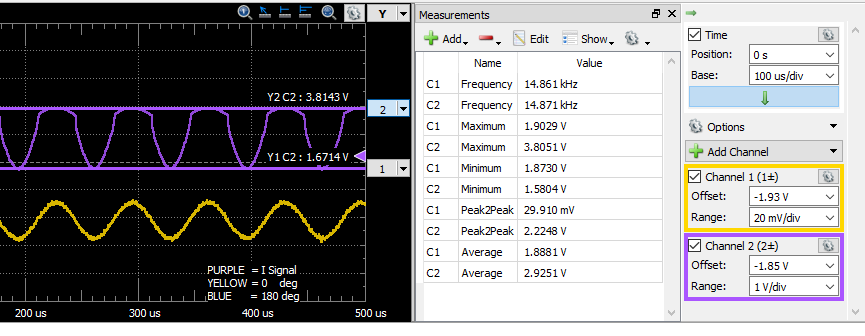
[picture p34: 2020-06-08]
images/Testing/InstTest_I-Sig_0deg.png

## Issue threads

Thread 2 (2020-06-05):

Arduino 5V Pin Voltage Too Low

KonradMcClure, 2020-06-05:
The voltage reads around 4.5V. There's probably something pulling more current than it should. After the BJT smoother, we're aiming for a voltage of about 4.3V, but with the drop from 5V causes it to be around 3.8-3.9V

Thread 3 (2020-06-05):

MUX Outputs at Different Offsets

KonradMcClure, 2020-06-05:
The I_0, I_180, Q_90, and Q_270 lines are not at equal voltage offsets, causing the I and Q signals to be about a full volt apart. Need to compare their offsets to GNDA and find a way to get those paths at as close resistances to each other as possible, while also averaging on GNDA...

KonradMcClure, 2020-06-07:
Took some screenshots releveant to both this issue and Issue #4
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

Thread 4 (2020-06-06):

Bandbase Signals Read ~14-15kHz rather than 10.7kHz

KonradMcClure, 2020-06-06:
The bandbase signals (0, 90, 180, 270 degrees) should come out of the MUX at 10.7kHz, yet they appear to be around 14-15kHz. This could be an issue with clock generator, speed of the johnson counter circuit, or the speed of the multiplexer itself...

KonradMcClure, 2020-06-07:
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

KonradMcClure, 2020-06-07:
Frequencies can be seen in the images above. They average around 14.8kHz, though the 90deg baseband appears to be at 15.3kHz...

KonradMcClure, 2020-06-09:
Did some testing to see what might be the cause. I dropped the RF frequency down to 5MHz, and the LO frequency to 5MHz + 10.7kHz. Reading the Baseband 180deg and the LO_I test pins I saw this:
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
Since the difference in LO - RF can be seen in these images to indeed be the the frequency of IF, we can rule out it's the MUX that's causing this issue.

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
Here I've taken a reading of the LO_I pin and CLK0 pin on the same settings. I'm stretching the sample rate of the Digilent Analog Discovery 2, which sits at a max of 100MHz, but it's relatively clear. We would expect that the CLK0 pin would read as 4*(5,000,000 + 10,700) = 20.042MHz which is what was put in the arduino code for the si5351 test. However over time we see it average out to 20.022 MHz (running longer than the image above). We only seem to be getting half of the 4*10,700 that we would expect. Luckily the Johnson counter seems to be pretty faithfully dividing by 4 given that 20.022/5.0134 = 3.994

KonradMcClure, 2020-06-09:
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
I set up the other outputs of the si5351 to see if they all read the same. It appears the Analog Discovery 2 reads a different value depending on whether my other probe is reading the other clock signals....
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
Or the local oscillator...
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
Or nothing on the other probe...

I think my equipment just might not be good enough for this

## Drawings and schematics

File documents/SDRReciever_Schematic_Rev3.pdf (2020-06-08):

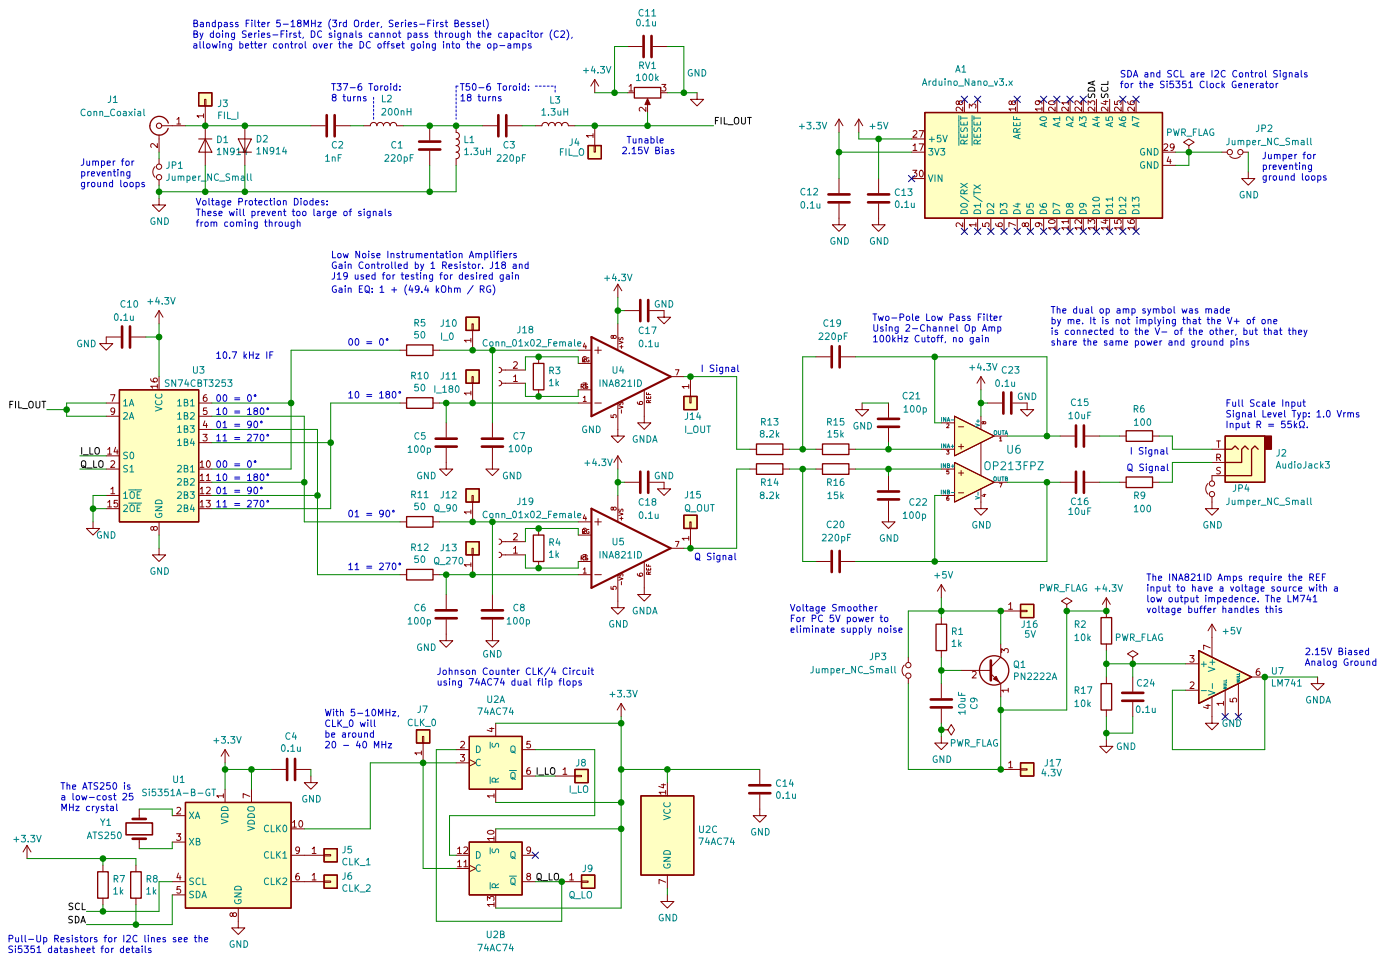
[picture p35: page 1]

Bandpass Filter 5-18MHz (3rd Order, Series-First Bessel)
By doing Series-First, DC signals cannot pass through the capacitor (C2),
allowing better control over the DC offset going into the op-amps

Voltage Protection Diodes:
These will prevent too large of signals
from coming through

Low Noise Instrumentation Amplifiers
Gain Controlled by 1 Resistor. J18 and

Gain EQ: 1 + (49.4 kOhm / RG)

The dual op amp symbol was made
by me. It is not implying that the V+ of one
is connected to the V- of the other, but that they
share the same power and ground pins

Full Scale Input
Signal Level Typ: 1.0 Vrms

input to have a voltage source with a
low output impedence. The LM741

voltage buffer handles this The ATS250 is a low-cost 25 MHz crystal

For PC 5V power to
eliminate supply noise

1 CLK0 10 XA 2 XB 3 SCL 4 SDA 5 CLK2 6 VDDO

Pull-Up Resistors for I2C lines see the Si5351 datasheet for details

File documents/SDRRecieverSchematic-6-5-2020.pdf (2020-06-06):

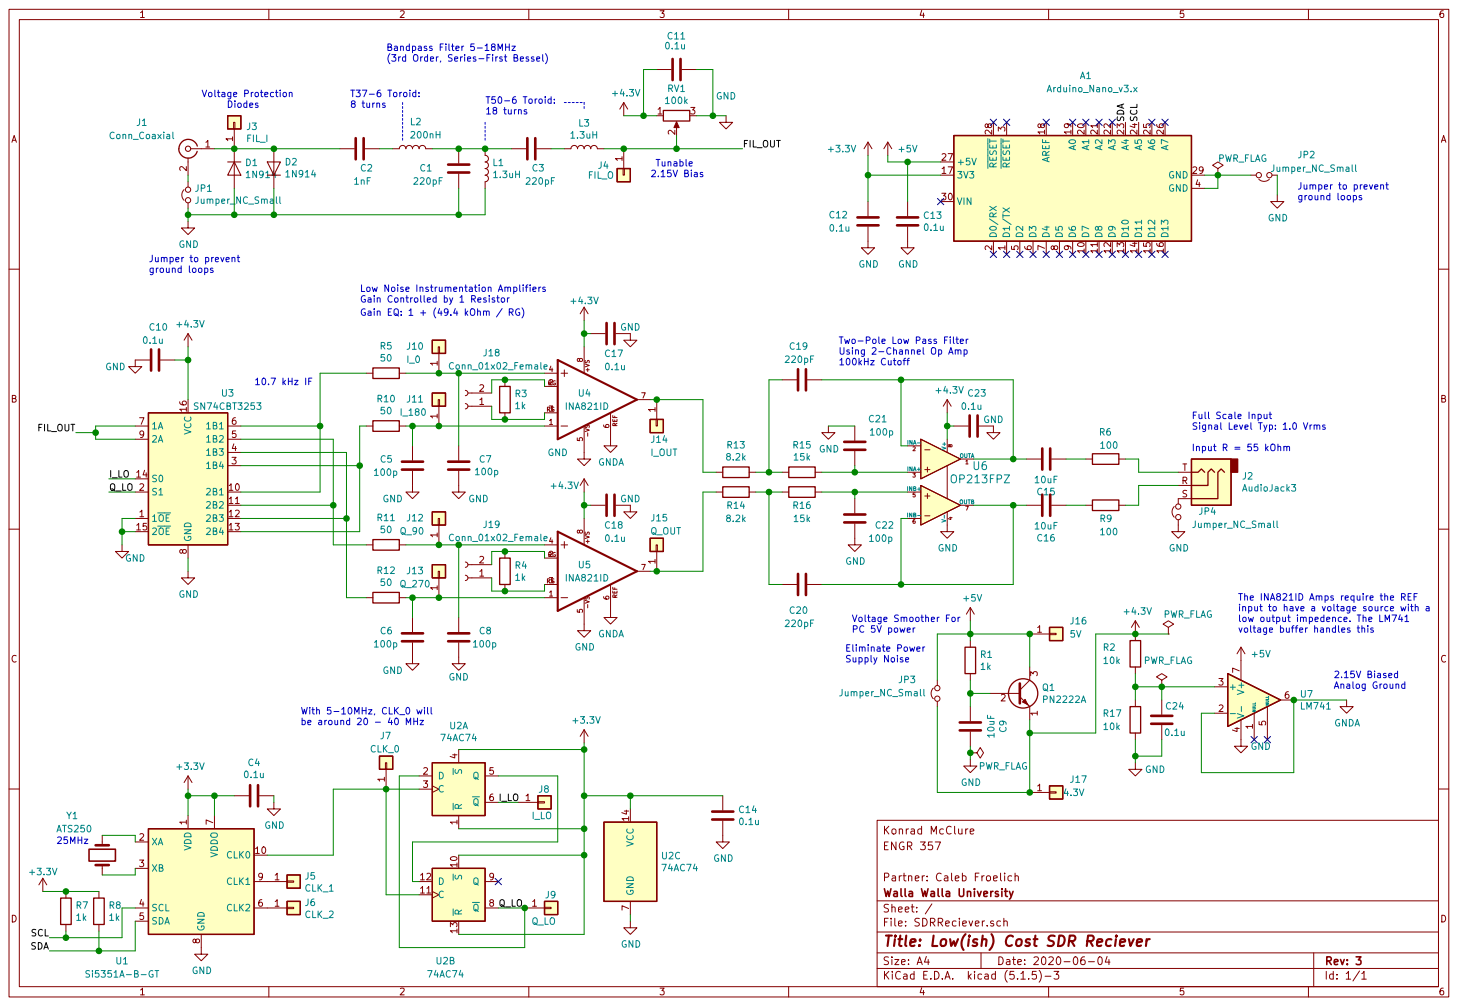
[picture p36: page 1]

(3rd Order, Series-First Bessel)

100kHz Cutoff Low Noise Instrumentation Amplifiers
Gain Controlled by 1 Resistor

Signal Level Typ: 1.0 Vrms

Voltage Smoother For
PC 5V power
Eliminate Power Supply Noise

input to have a voltage source with a
low output impedence. The LM741

Id: 1/1 Title: Low(ish) Cost SDR Reciever File: SDRReciever.sch Sheet: / Walla Walla University Partner: Caleb Froelich ENGR 357 Konrad McClure GND

1 CLK0 10 XA 2 XB 3 SCL 4 SDA 5 CLK2 6 VDDO

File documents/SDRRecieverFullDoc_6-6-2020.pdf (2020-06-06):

Walla Walla University

# SDR Receiver Project

ENGR 357 – Electronics II
Konrad McClure
Partner: Caleb Froelich
Professor: Dr. Rob Frohne
Spring 2020

## Abstract

The goal of this project was to design a low-cost software-defined radio (SDR) receiver in a team of two. The SDR receiver connects to an antenna and covers the filtering, mixing, and amplification of the desired signal. It then connects a sound card within a computer and software handles the demodulation of the signal into playable audio. The mixing is handled using an Arduino Nano running code provided to us by Professor Frohne, which interfaces with Quisk, an SDR radio program that controls the receiver through the Arduino. Using Quisk, the radio can be tuned to a certain frequency by adjusting the speed of the local oscillator used in the mixing process. Our budget on this project to keep with the low-cost aspect was about $30 including fabrication of the PCB and the required components.

## Circuit Description

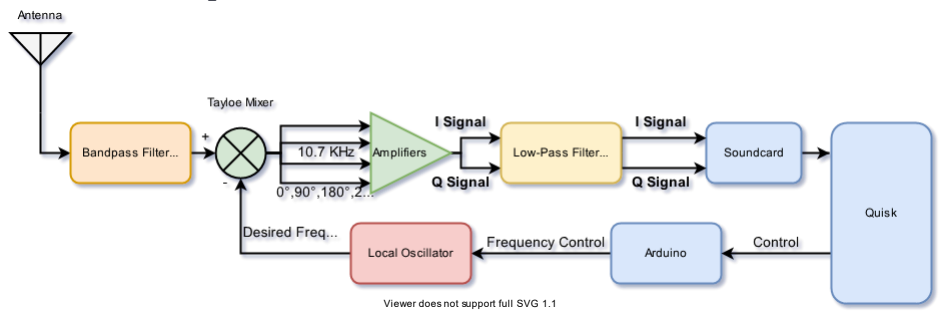
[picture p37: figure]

## Schematic

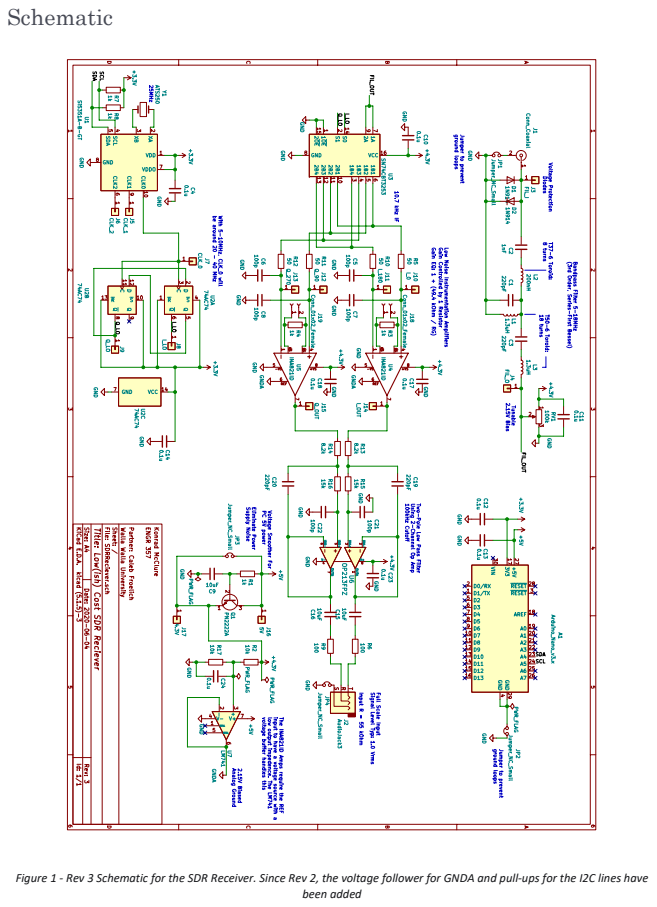
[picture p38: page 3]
been added

Figure 1 - Rev 3 Schematic for the SDR Receiver. Since Rev 2, the voltage follower for GNDA and pull-ups for the I2C lines have

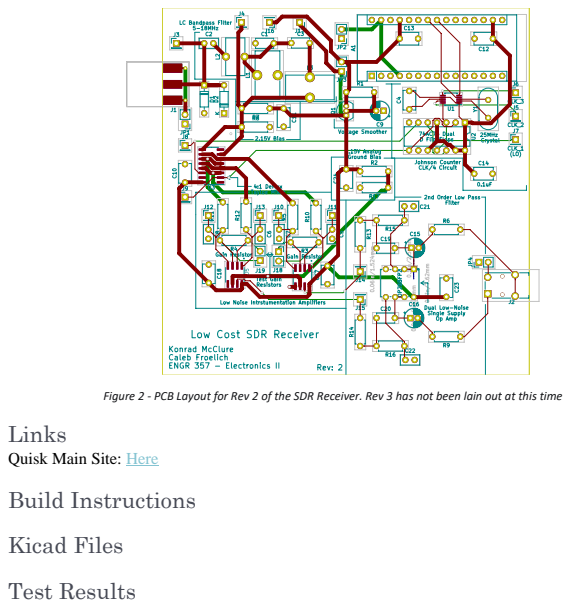
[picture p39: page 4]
Kicad Files; Test Results

Figure 2 - PCB Layout for Rev 2 of the SDR Receiver. Rev 3 has not been lain out at this time

Links
Quisk Main Site: Here (https://james.ahlstrom.name/quisk/)
Build Instructions

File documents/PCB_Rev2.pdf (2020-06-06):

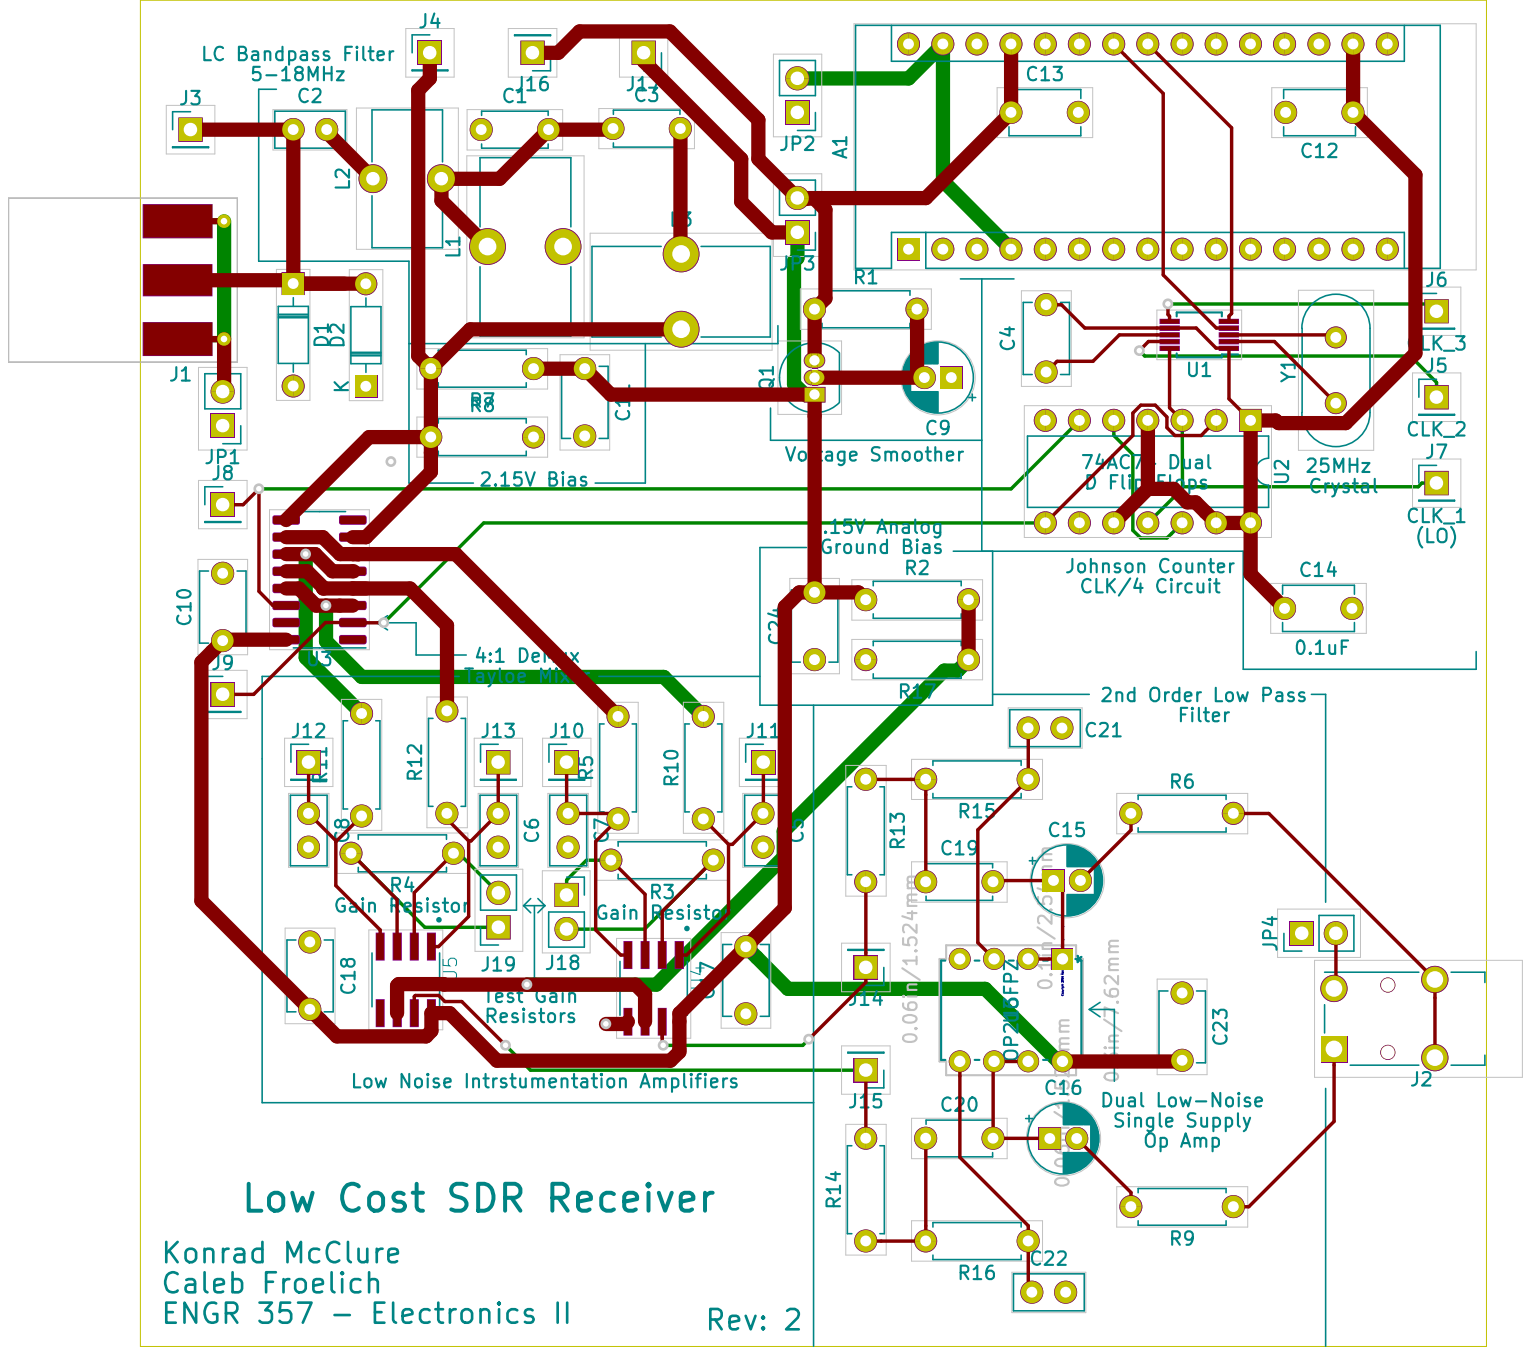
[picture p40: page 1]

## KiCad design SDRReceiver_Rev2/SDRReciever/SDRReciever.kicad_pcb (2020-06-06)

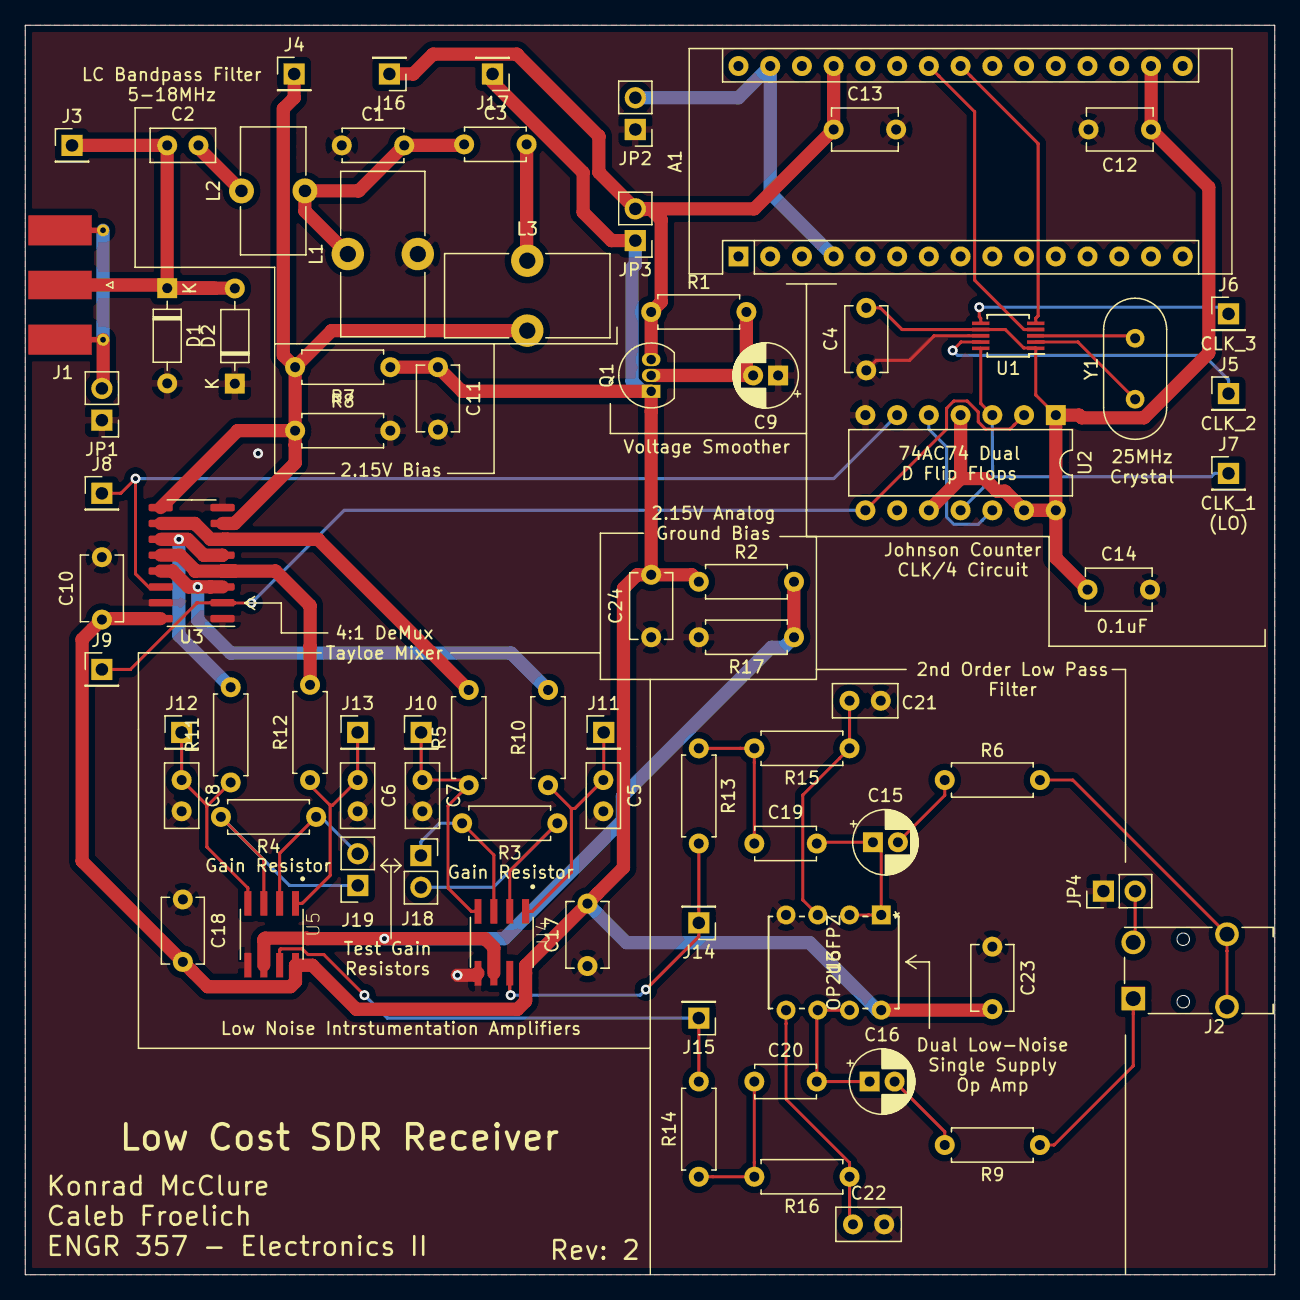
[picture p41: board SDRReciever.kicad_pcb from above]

Board: 2 copper layers, 100.0 x 100.0 mm, 78 parts (0 on the bottom side), 48 nets.

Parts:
A1: Arduino_Nano_v3.x; Arduino_Nano
C1, C3: 220pF; C_Disc_D4.7mm_W2.5mm_P5.00mm
C2: 1nF; C_Disc_D5.0mm_W2.5mm_P2.50mm
C4, C10, C11, C12, C13, C14, C17, C18, C23, C24: 0.1u; C_Disc_D5.1mm_W3.2mm_P5.00mm
C5, C6, C7, C8, C21, C22: 100p; C_Disc_D5.0mm_W2.5mm_P2.50mm
C9, C15, C16: 10uF; CP_Radial_D5.0mm_P2.00mm
C19, C20: 220p; C_Disc_D4.7mm_W2.5mm_P5.00mm
D1, D2: 1N914; D_DO-35_SOD27_P7.62mm_Horizontal
J1: Conn_Coaxial; SMA_Molex_73251-1153_EdgeMount_Horizontal
J2: AudioJack3; Jack_3.5mm_Switronic_ST-005-G_horizontal
J3: FIL_I; PinHeader_1x01_P2.54mm_Vertical
J4: FIL_O; PinHeader_1x01_P2.54mm_Vertical
J5: CLK_2; PinHeader_1x01_P2.54mm_Vertical
J6: CLK_3; PinHeader_1x01_P2.54mm_Vertical
J7: CLK_1; PinHeader_1x01_P2.54mm_Vertical
J8: I_LO; PinHeader_1x01_P2.54mm_Vertical
J9: Q_LO; PinHeader_1x01_P2.54mm_Vertical
J10: I_0; PinHeader_1x01_P2.54mm_Vertical
J11: I_180; PinHeader_1x01_P2.54mm_Vertical
J12: Q_90; PinHeader_1x01_P2.54mm_Vertical
J13: Q_270; PinHeader_1x01_P2.54mm_Vertical
J14: I_OUT; PinHeader_1x01_P2.54mm_Vertical
J15: Q_OUT; PinHeader_1x01_P2.54mm_Vertical
J16: 5V; PinHeader_1x01_P2.54mm_Vertical
J17: 4.3V; PinHeader_1x01_P2.54mm_Vertical
J18, J19: Conn_01x02_Female; PinSocket_1x02_P2.54mm_Vertical
JP1, JP2, JP3, JP4: Jumper_NC_Small; PinHeader_1x02_P2.54mm_Vertical
L1, L3: 1.3uH; L_Toroid_Vertical_L13.0mm_W6.5mm_P5.60mm
L2: 200nH; L_Toroid_Vertical_L10.0mm_W5.0mm_P5.08mm
Q1: PN2222A; TO-92_Inline
R1: 1k; R_Axial_DIN0207_L6.3mm_D2.5mm_P7.62mm_Horizontal
R2, R7, R8, R17: 10k; R_Axial_DIN0207_L6.3mm_D2.5mm_P7.62mm_Horizontal
R3, R4: 33; R_Axial_DIN0207_L6.3mm_D2.5mm_P7.62mm_Horizontal
R5, R10, R11, R12: 50; R_Axial_DIN0207_L6.3mm_D2.5mm_P7.62mm_Horizontal
R6, R9: 100; R_Axial_DIN0207_L6.3mm_D2.5mm_P7.62mm_Horizontal
R13, R14: 8.2k; R_Axial_DIN0207_L6.3mm_D2.5mm_P7.62mm_Horizontal
R15, R16: 15k; R_Axial_DIN0207_L6.3mm_D2.5mm_P7.62mm_Horizontal
U1: Si5351A-B-GT; MSOP-10_3x3mm_P0.5mm
U2: 74AC74; DIP-14_W7.62mm
U3: SN74CBT3253; SOIC-16_3.9x9.9mm_P1.27mm
U4, U5: INA821ID; SOIC127P600X175-8N
U6: OP213FPZ
Y1: Crystal; Crystal_HC49-U_Vertical

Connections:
+3V3: A1.17, C4.2, C12.1, C14.1, U1.1, U1.7, U2.1, U2.4, U2.10, U2.13, U2.14
+4.3V: C10.1, C11.1, C17.2, C18.2, C23.2, C24.2, J17.1, JP3.1, Q1.1, R2.1, R7.1, U3.16, U4.8, U5.8, U6.8
+5V: A1.27, C13.1, J16.1, JP3.2, Q1.3, R1.1
/FIL_OUT: J4.1, L3.2, R7.2, R8.1, U3.7, U3.9
/I_LO: J8.1, U2.6, U3.14
/Q_LO: J9.1, U2.2, U2.8, U3.2
/SCL: A1.24, U1.4
/SDA: A1.23, U1.5
GND: C1.1, C4.1, C5.2, C6.2, C7.2, C8.2, C9.1, C10.2, C11.2, C12.2, C13.2, C14.2, C17.1, C18.1, C21.2, C22.2, C23.1, C24.1, D1.2, D2.1, JP1.1, JP2.1, JP4.1, L1.2, R8.2, R17.2, U1.8, U2.7, U3.1, U3.8, U3.15, U4.5, U5.5, U6.4
GNDA: R2.2, R17.1, U4.6, U5.6
unnamed: A1.4, A1.29, JP2.2
unnamed: C1.2, C3.1, L1.1, L2.2
unnamed: C2.1, D1.1, D2.2, J1.1, J3.1
unnamed: C2.2, L2.1
unnamed: C3.2, L3.1
unnamed: C5.1, J11.1, R10.1, U4.1
unnamed: C6.1, J13.1, R12.1, U5.1
unnamed: C7.1, J10.1, R5.1, U4.4
unnamed: C8.1, J12.1, R11.1, U5.4
unnamed: C9.2, Q1.2, R1.2
unnamed: C15.1, C19.2, U6.1, U6.2
unnamed: C15.2, R6.1
unnamed: C16.1, C20.2, U6.6, U6.7
unnamed: C16.2, R9.2
unnamed: C19.1, R13.1, R15.2
unnamed: C20.1, R14.1, R16.2
unnamed: C21.1, R15.1, U6.3
unnamed: C22.1, R16.1, U6.5
unnamed: J1.2, JP1.2
unnamed: J2.R, R9.1
unnamed: J2.S, JP4.2
unnamed: J2.T, R6.2
unnamed: J5.1, U1.9
unnamed: J6.1, U1.6
unnamed: J7.1, U1.10, U2.3, U2.11
unnamed: J14.1, R13.2, U4.7
unnamed: J15.1, R14.2, U5.7
unnamed: J18.1, R3.2, U4.3
unnamed: J18.2, R3.1, U4.2
unnamed: J19.1, R4.2, U5.3
unnamed: J19.2, R4.1, U5.2
unnamed: R5.2, U3.6, U3.10
unnamed: R10.2, U3.3, U3.13
unnamed: R11.2, U3.5, U3.11
unnamed: R12.2, U3.4, U3.12
unnamed: U1.2, Y1.1
unnamed: U1.3, Y1.2
unnamed: U2.5, U2.12

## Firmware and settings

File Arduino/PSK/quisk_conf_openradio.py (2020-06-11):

# OpenRadio v1.1 Quisk Configuration File
# 
# IMPORTANT: To be able to control the OpenRadio board from within Quisk,
# you will need to compile and upload the 'openradio_quisk' firmware, which
# is available from: https://github.com/darksidelemm/open_radio_miniconf_2015
#
# You will also need to install the pyserial package for python.
#

from __future__ import print_function
from __future__ import absolute_import
from __future__ import division


# SOUND CARD SETTINGS
#
# Uncomment these if you wish to use PortAudio directly
#name_of_sound_capt = "portaudio:(hw:2,0)"
#name_of_sound_play = "portaudio:(hw:1,0)"

# Uncomment these lines if you wish to use Pulseaudio
name_of_sound_capt = "pulse"
name_of_sound_play = "pulse"

# SERIAL PORT SETTINGS
# Set this as appropriate for your OS.
openradio_serial_port = "COM5"
openradio_serial_rate = 57600


# OpenRadio Frequency limits.
# These are just within the limits set in the openradio_quisk firmware.
openradio_lower = 3000000
openradio_upper = 12000000

# OpenRadio Hardware Control Class
#
import serial,time
from quisk_hardware_model import Hardware as BaseHardware

class Hardware(BaseHardware):
  def open(self):
    # Called once to open the Hardware
    # Open the serial port.
    self.or_serial = serial.Serial(openradio_serial_port,openradio_serial_rate,timeout=3)
    print("Opened Serial Port.")
    # Wait for the Arduino Nano to restart and boot.
    time.sleep(2)
    # Poll for version. Should probably confirm the response on this.
    version = str(self.get_parameter("VER"))
    print("This should be the version printed next.")
    print(version)
    # Return an informative message for the config screen
    t = version + ". Capture from sound card %s." % self.conf.name_of_sound_capt
    return t

  def close(self):      
    # Called once to close the Hardware
    self.or_serial.close()

  def ChangeFrequency(self, tune, vfo, source='', band='', event=None):
    # Called whenever quisk requests a frequency change.
    # This sends the FREQ command to set the centre frequency of the OpenRadio,
    # and will also move the 'tune' frequency (the section within the RX passband
    # which is to be demodulated) if it falls outside the passband (+/- sample_rate/2).
    print("Setting VFO to %d." % vfo)
    if(vfo<openradio_lower):
      vfo = openradio_lower
      print("Outside range! Setting to %d" % openradio_lower)

    if(vfo>openradio_upper):
      vfo = openradio_upper
      print("Outside range! Setting to %d" % openradio_upper)

    success = self.set_parameter("FREQ",str(vfo))

    print("sample_rate =")
    print(sample_rate)
    # If the tune frequency is outside the RX bandwidth, set it to somewhere within that bandwidth.
    if(tune>(vfo + sample_rate/2) or tune<(vfo - sample_rate/2)):
      tune = vfo + 10000
      print("Bringing tune frequency back into the RX bandwidth.")

    if success:
      print("Frequency change succeeded!")
    else:
      print("Frequency change failed.")

    return tune, vfo

#
# Serial comms functions, to communicate with the OpenRadio board
#

  def get_parameter(self,string):
    string = string + "\n"
    self.or_serial.write(string.encode())
    return self.get_argument()
    #return string.encode()
        
  def set_parameter(self,string,arg):
    string = string+","+arg+"\n"
    self.or_serial.write(string.encode())
    if self.get_argument() == arg:
      return True
    else:
      return False
    
  def get_argument(self):
    data1 = self.or_serial.readline()
    # Do a couple of quick checks to see if there is useful data here
    if len(data1) == 0:
       return -1
        
    # Maybe we didn't catch an OK line?
    if data1.startswith(b'OK'):
       data1 = self.or_serial.readline()
        
    # Check to see if we have a comma in the string. If not, there is no argument.
    if data1.find(b',') == -1:
       return -1
    
    data1 = data1.split(b',')[1].rstrip(b'\r\n')
    print("data1 =")
    print(data1)
    
    # Check for the OK string
    data2 = self.or_serial.readline()
    if data2.startswith(b'OK'):
       return data1

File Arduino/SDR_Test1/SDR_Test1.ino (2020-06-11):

#include "si5351.h"
#include "Wire.h"

Si5351 si5351;

void setup()
{
  bool i2c_found;
  i2c_found = si5351.init(SI5351_CRYSTAL_LOAD_8PF, 0, 0);
  si5351.set_freq(4*(500000000ULL + 1070000ULL), SI5351_CLK0);
  si5351.set_freq(4*(500000000ULL + 1070000ULL), SI5351_CLK1);
  si5351.set_freq(4*(500000000ULL + 1070000ULL), SI5351_CLK2);
  Serial.begin(115200);
}

//1070000ULL


void loop()
{
  si5351.update_status();
  Serial.print("SYS_INIT: ");
  Serial.print(si5351.dev_status.SYS_INIT);
  Serial.print("  LOL_A: ");
  Serial.print(si5351.dev_status.LOL_A);
  Serial.print("  LOL_B: ");
  Serial.print(si5351.dev_status.LOL_B);
  Serial.print("  LOS: ");
  Serial.print(si5351.dev_status.LOS);
  Serial.print("  REVID: ");
  Serial.println(si5351.dev_status.REVID);
}

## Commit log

2020-06-05 new file: BOMs/CalebSDRReceiver_BOM.csv new file: BOMs/KonradSDRReceiver_BOM.csv new file: BOMs/SDRReceiverCartBOM_FroelichMcClure.xlsx new file: BOMs/SDRReceiverDigikeyBOM_FroelichMcClure.csv new fi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
    [CalebSDRReceiver_BOM.csv, KonradSDRReceiver_BOM.csv, SDRBackup.kicad_pcb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]
2020-06-05 Added images
    [SDRReciever.kicad_pcb]
2020-06-05 Add Board Render to readme
2020-06-05 Added potentiometer, voltage buffer, clk gen pull up resistors, comments, and corrected gain resistors to 1k
    [SDRReciever.sch]
2020-06-05 Added ltspice sims, revision document, image of the prototype, made some changes to the schematic (i believe just the title block)
    [SDRReciever.sch]
2020-06-06 Changed PCB silkscreen title block, renamed some image files to be more specific to the revision they refer to, added SVGs for clearer documentation imagery
    [SDRReciever.kicad_pcb, SDRReciever.sch]
2020-06-06 Added notes to schematic and more images
    [SDRReciever.sch]
2020-06-07 Fixed board render link
2020-06-07 Added issue4 testing images
    [SDRReciever.sch]
2020-06-08 New board render
2020-06-08 Organized images and added schematic images
2020-06-08 Added images from schematic
2020-06-09 Added small versions of prototype images
2020-06-09 Added Rev2 full schem
    [SDRReciever.sch]
2020-06-09 Added full schematic to readme
2020-06-09 Added Rev2 Project to it's own folder
    [CalebSDRReceiver_BOM.csv, KonradSDRReceiver_BOM.csv, SDRBackup.kicad_pcb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]
2020-07-08 Fixed the Rev2 schematic from being pulled apart for screenshots
    [SDRReciever.kicad_pcb, SDRReciever.sch]

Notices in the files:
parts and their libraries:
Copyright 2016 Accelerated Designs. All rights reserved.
